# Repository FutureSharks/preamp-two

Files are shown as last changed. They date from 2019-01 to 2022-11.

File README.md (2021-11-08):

# Preamp Two



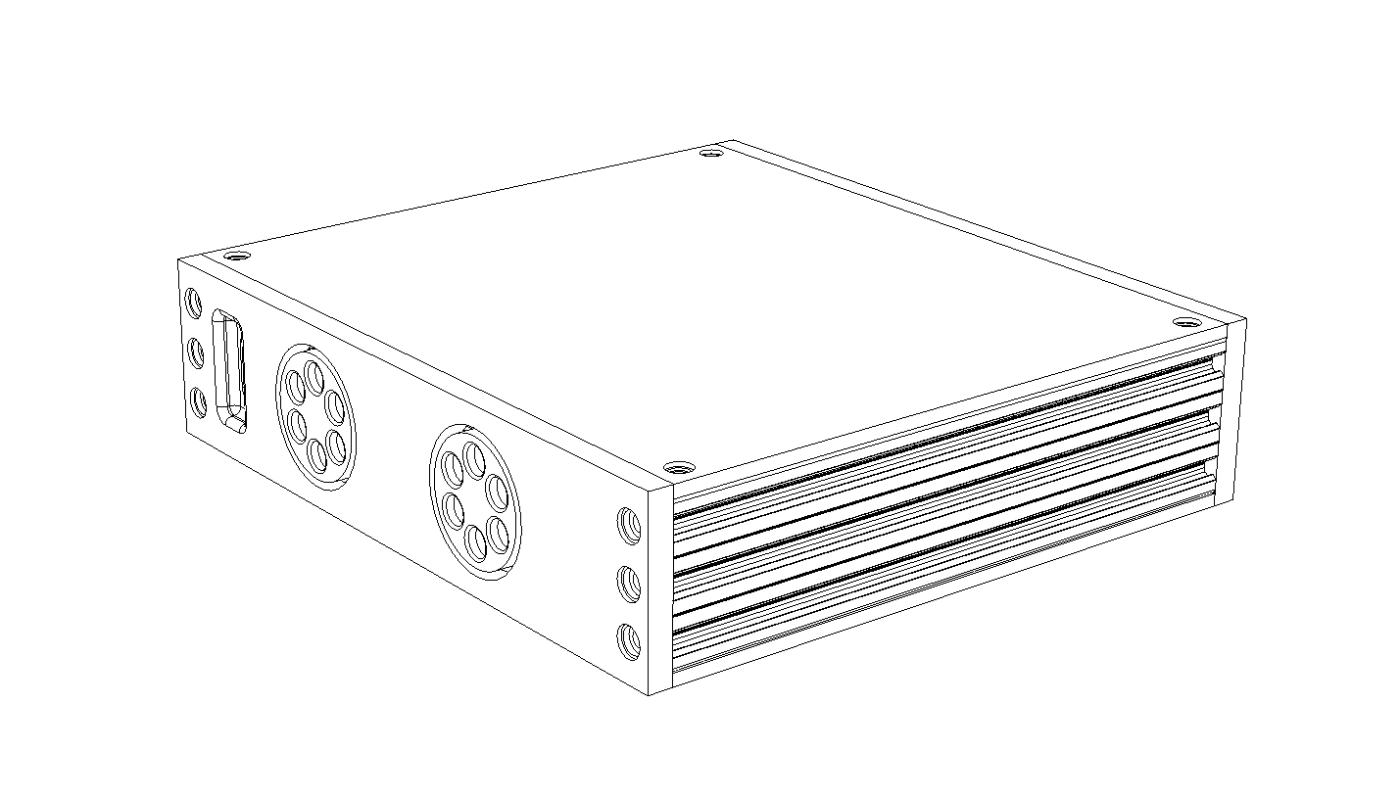
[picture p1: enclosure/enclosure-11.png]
complete


Here is my Hi-Fi preamplifier project. In this repository you can find schematics, PCB layouts, CircuitPython code, BoMs, measurements and photos.

Features:

* MDAC volume controller
* 6 way relay based input selector
* High performance design with measurements
* Quality components and modular design
* Completely digitally controlled
* All open source and written in Python

## Components and code

The preamplifier is made up of a number of connected components:

* MDAC attenuator ([PCB](PCBs/mdac-attenuator), [code](code/modules/mdac_attenuator.py)): Controls the volume
* Input selector ([PCB](PCBs/input-selector), [code](code/modules/input_selector.py)): Selects the input
* Encoder panel ([PCB](PCBs/encoder-panel), [code](code/modules/encoder_panel.py)): Holds rotary encoder and LED indicator ring
* Power Supply 5V ([PCB](PCBs/psu-digital)): Power supply for digital components.
* Power Supply +/- 15V ([PCB](PCBs/psu-analog)): Analog Power supply for MDAC attenuator
* Micro controller board ([PCB](PCBs/mcu-board), [code](code/main.py)): Holds the [Itsy Bitsy M4 Express](https://learn.adafruit.com/introducing-adafruit-itsybitsy-m4?view=all) and other connectors
* RCA panel ([PCB](PCBs/rca-panel)): For the RCA sockets and connectors

The PCBs and schematics were created in [KiCad](http://kicad.org/) and the code that runs on the micro controller is [CircuitPython](https://circuitpython.org/).

## Enclosure

Diagrams, CAD files and other information can be found here: [enclosure](enclosure)

## Measurements

THD, S/N ratio and power consumption: [measurements](measurements)

## Prototypes and testing

See here for a number of different [prototypes](prototypes). All PCBs were made by [OSH Park](https://oshpark.com/).

## Photos

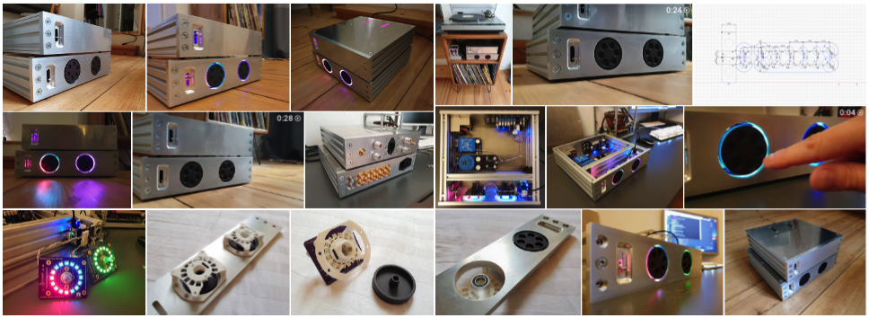
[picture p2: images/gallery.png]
photos


---

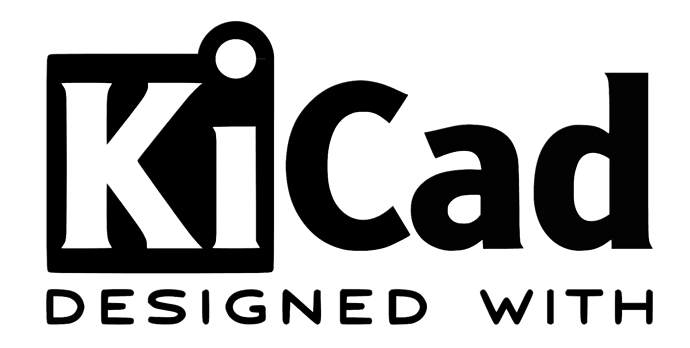
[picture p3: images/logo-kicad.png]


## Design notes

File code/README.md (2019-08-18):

# Code



Here is the code to run on a [CircuitPython](https://circuitpython.org/) micro-controller. Written and tested with Version 4.1.

To copy the code to the micro-controller:

```
cp -a code/modules code/main.py /Volumes/CIRCUITPY/
```

## Modules

- `modules/encoder_panel.py`: Controls the NeoPixel ring and reads the rotary encoder
- `modules/input_selector.py`: Controls the input selector hardware
- `modules/mdac_attenuator.py`: Controls the input attenuator hardware
- `modules/volume_control.py`: Manages the volume control interface
-	`modules/input_control.py`: Manages the input selector interface

---



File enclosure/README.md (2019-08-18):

# Enclosure



The enclosure is based around 2060 extrusion profile. You can buy it at many places. I bought mine [from Aliexpress](https://www.aliexpress.com/wholesale?SearchText=2060%20extrusion) where many sellers will cut custom lengths. It's a great thing to build things from because it's relatively cheap, you can tap an M6 thread into the ends and there's many brackets and attachments available specifically for the whole family of 20xx extrusions.

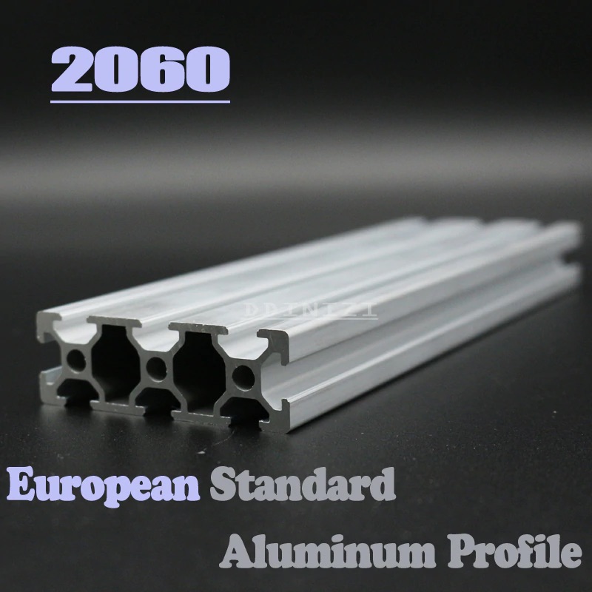
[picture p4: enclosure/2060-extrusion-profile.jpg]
2060-extrusion


## CAD files

Knobs and bearing bracket were made by [Shapeways](https://www.shapeways.com/).

Fusion 360 archive file: [preamp-two-enclosure.f3d](https://github.com/FutureSharks/preamp-two/raw/master/enclosure/preamp-two-enclosure.f3d)

STL of front: [front.stl](front.stl)

STL of rear: [rear.stl](rear.stl)

STL of knob: [knob.stl](knob.stl)

STL of knob and bearing bracket: [bearing-bracket.stl](bearing-bracket.stl)

## Photos



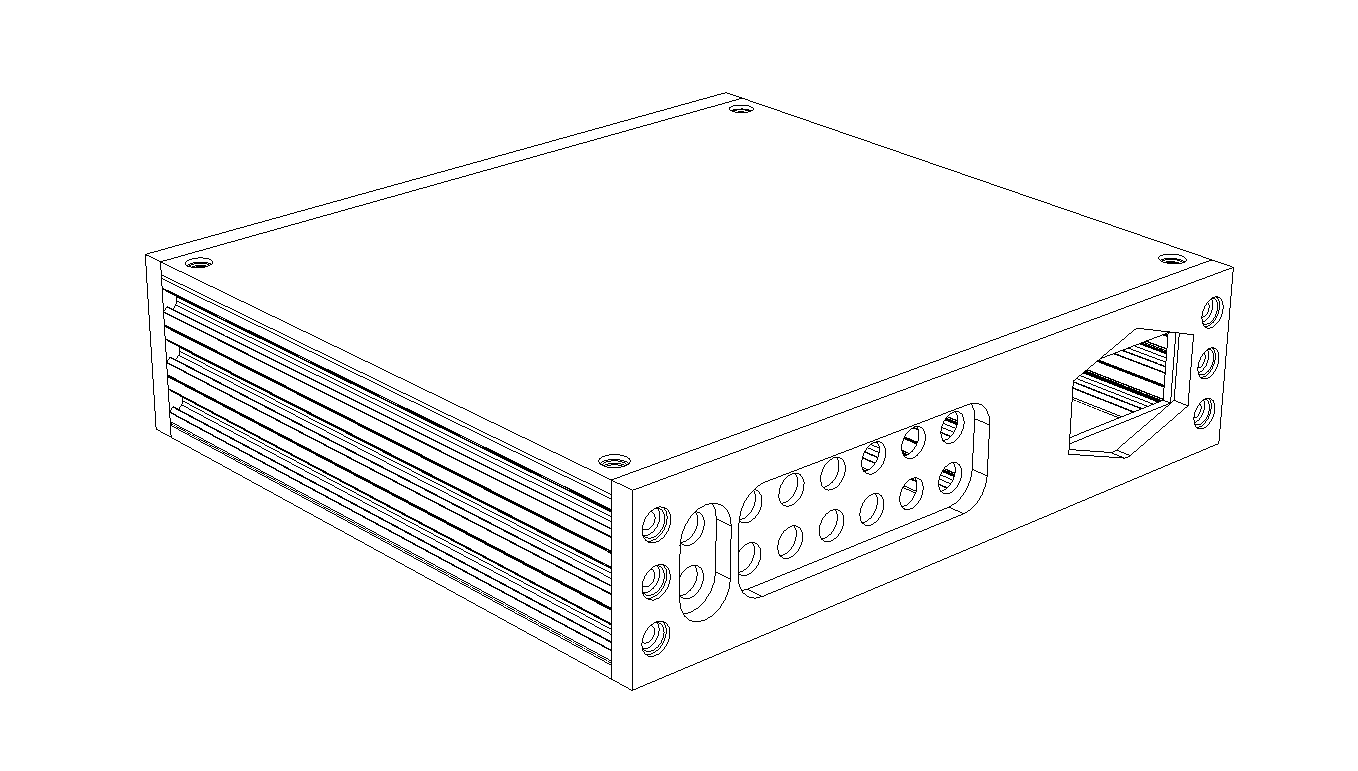
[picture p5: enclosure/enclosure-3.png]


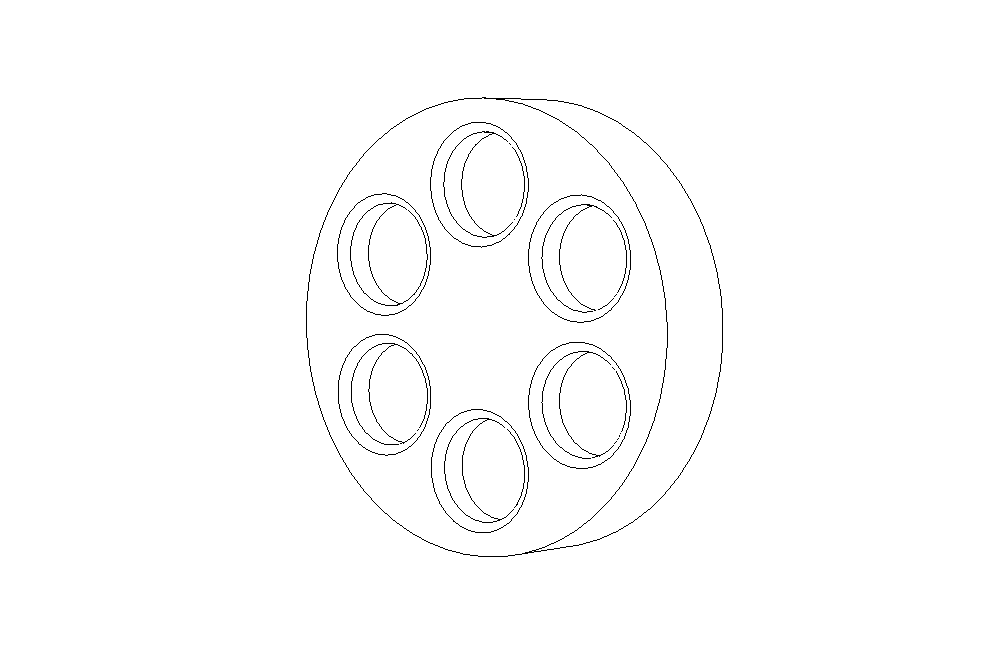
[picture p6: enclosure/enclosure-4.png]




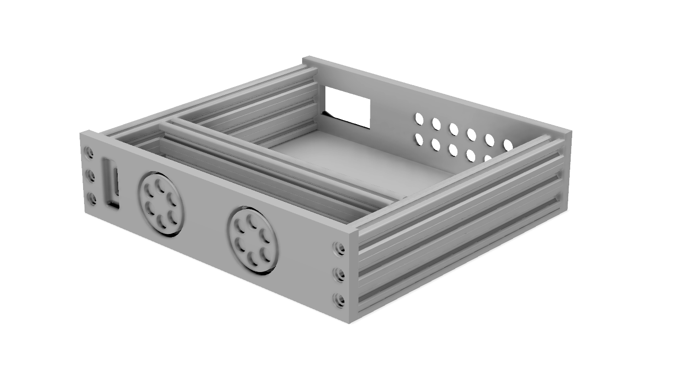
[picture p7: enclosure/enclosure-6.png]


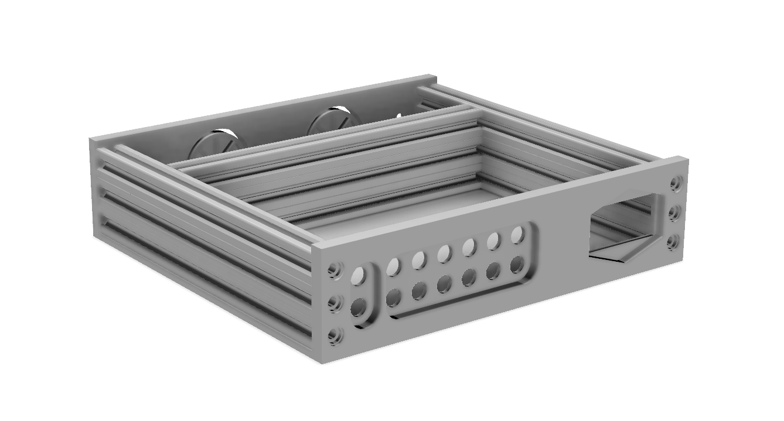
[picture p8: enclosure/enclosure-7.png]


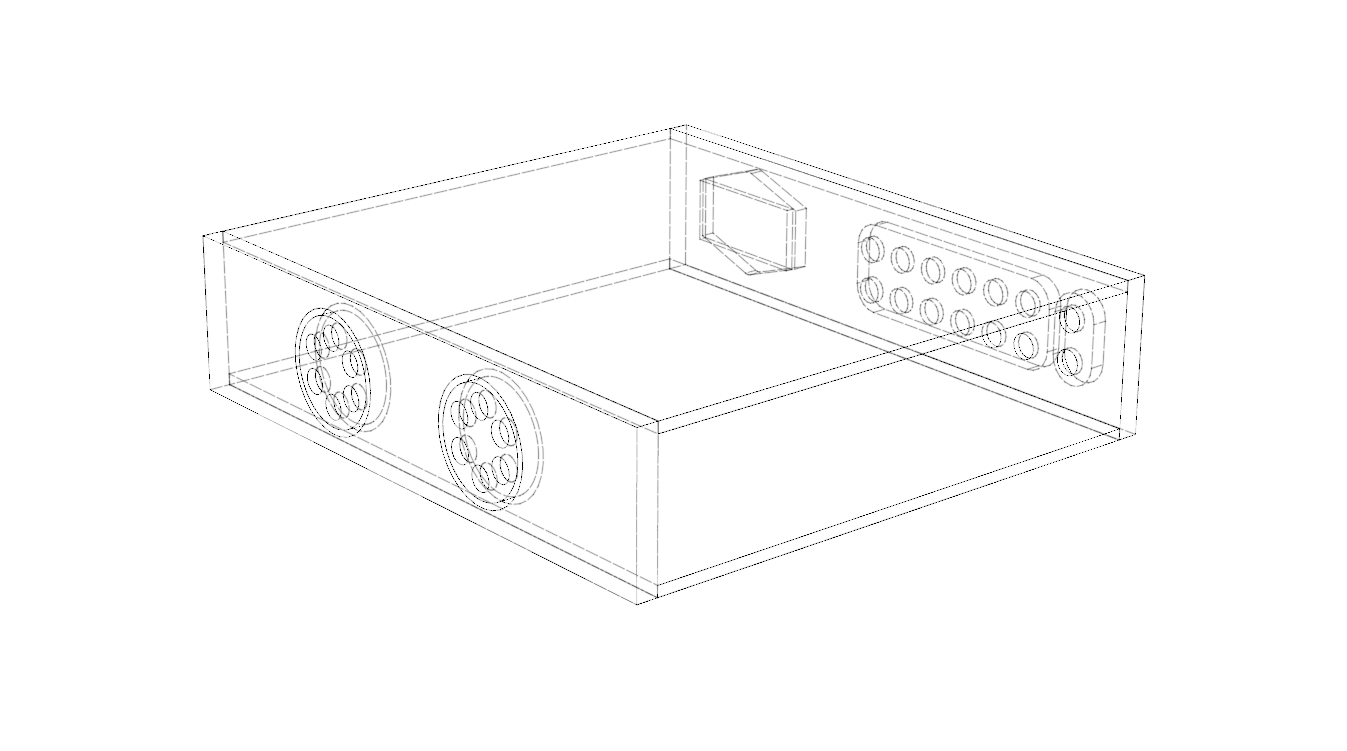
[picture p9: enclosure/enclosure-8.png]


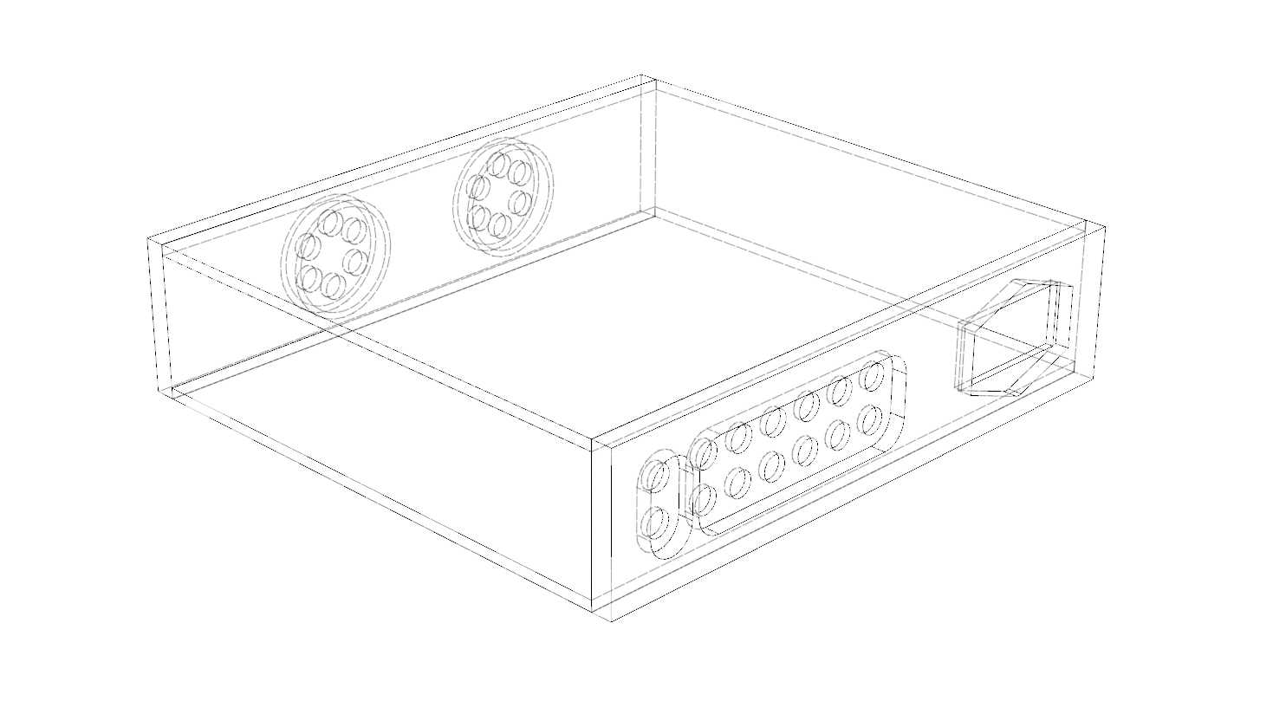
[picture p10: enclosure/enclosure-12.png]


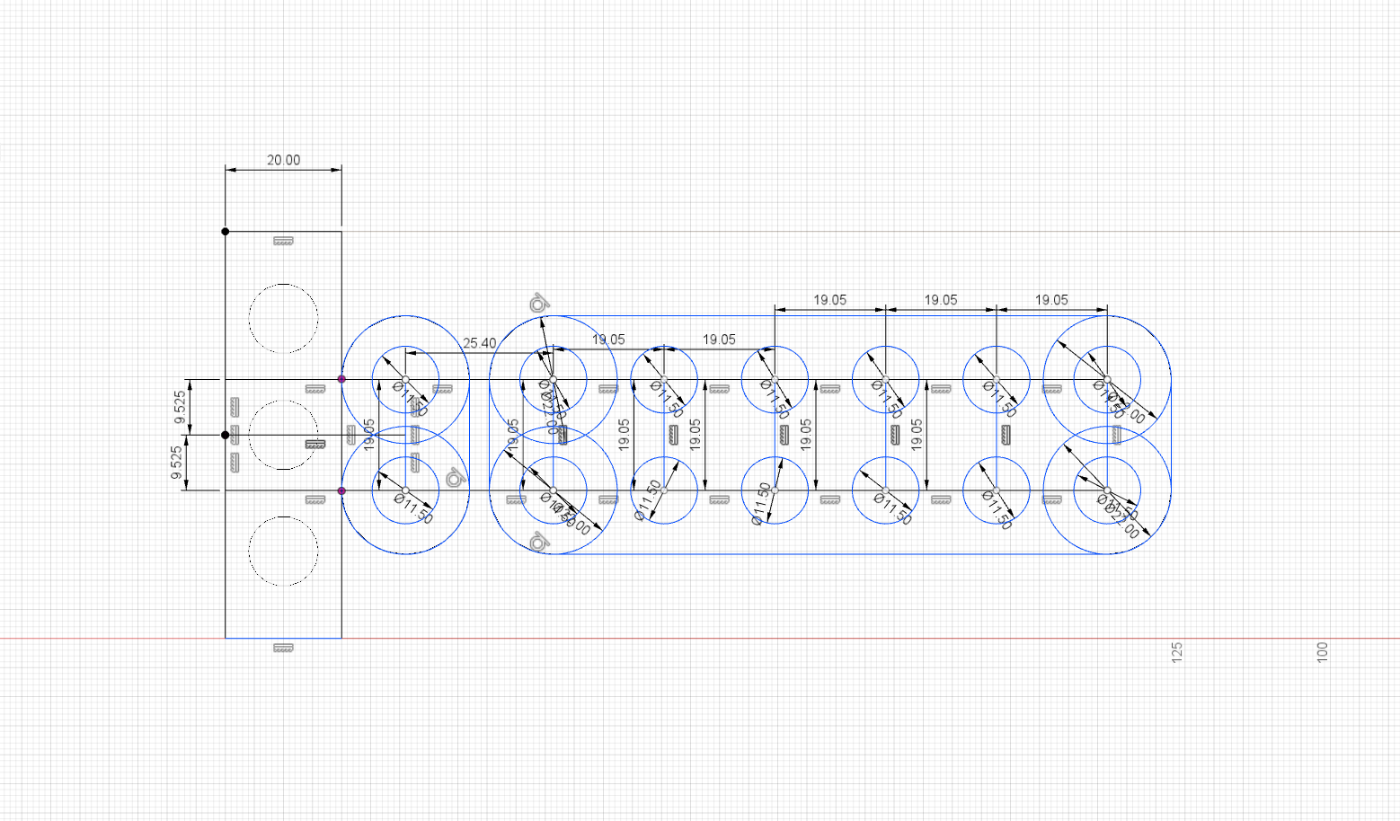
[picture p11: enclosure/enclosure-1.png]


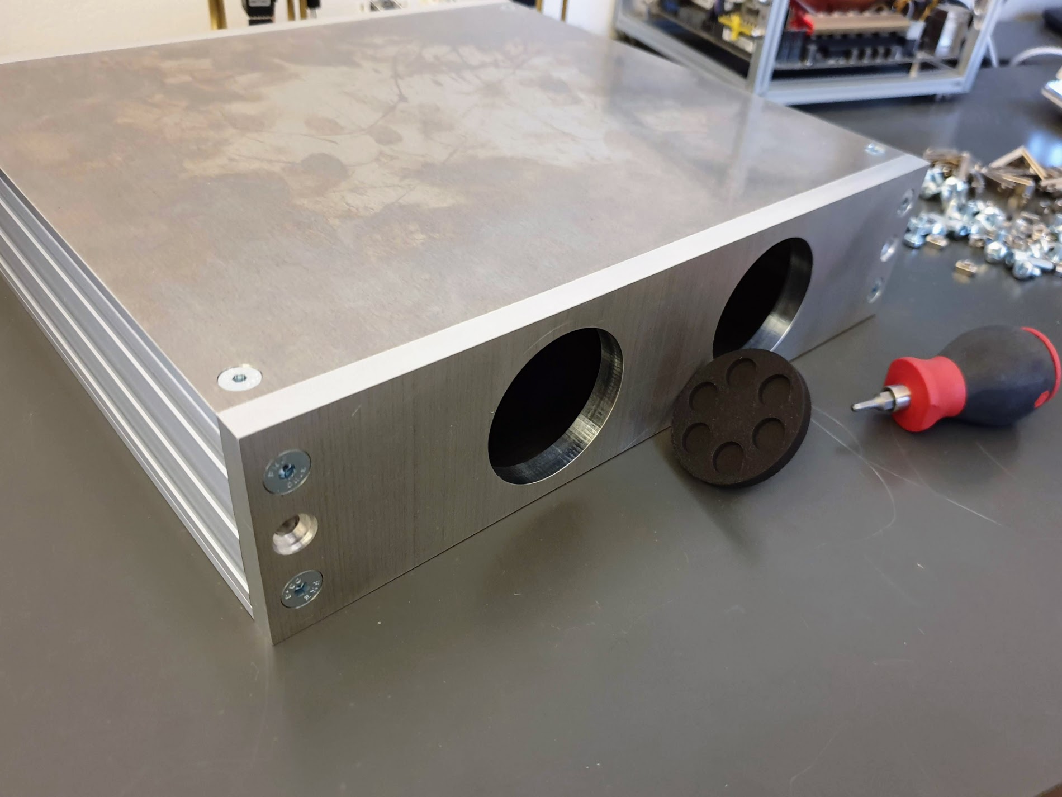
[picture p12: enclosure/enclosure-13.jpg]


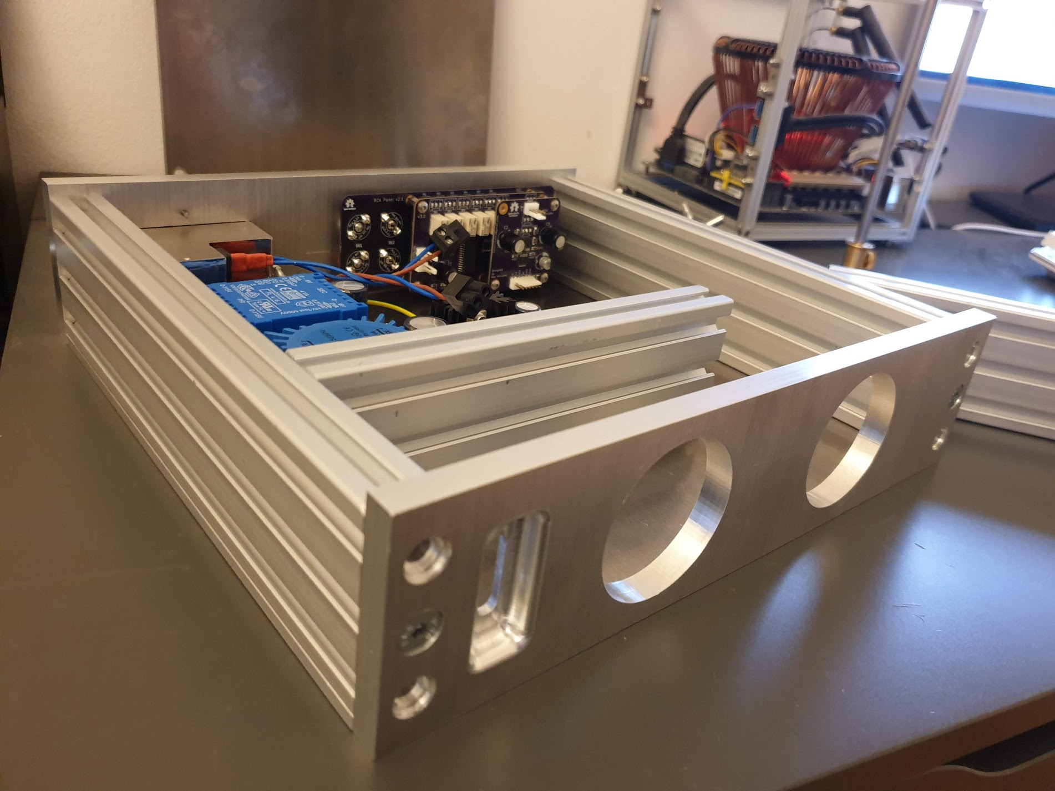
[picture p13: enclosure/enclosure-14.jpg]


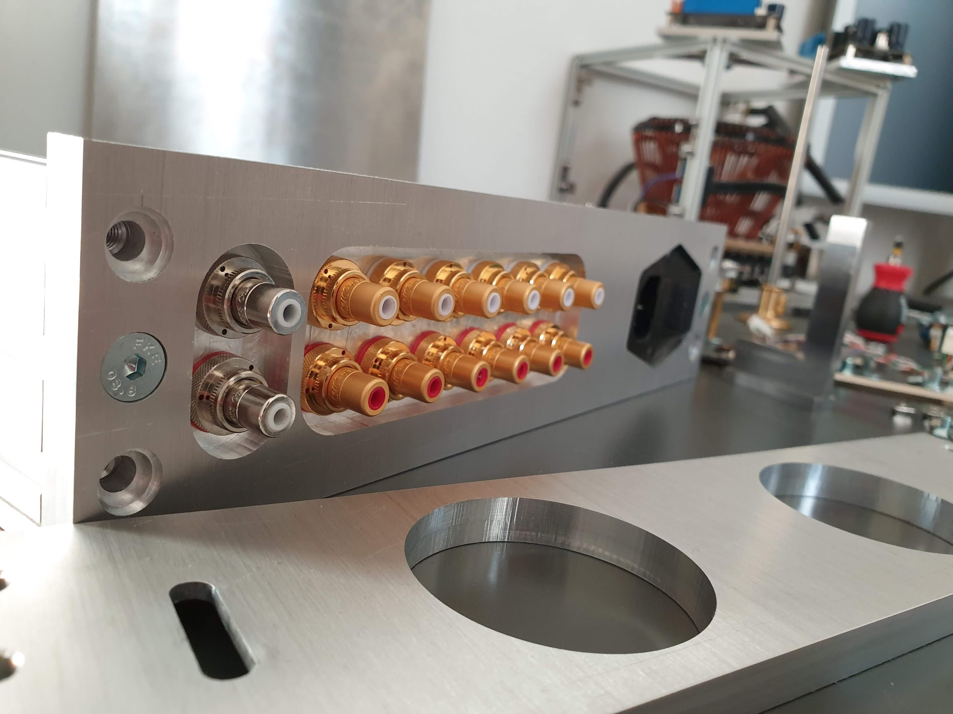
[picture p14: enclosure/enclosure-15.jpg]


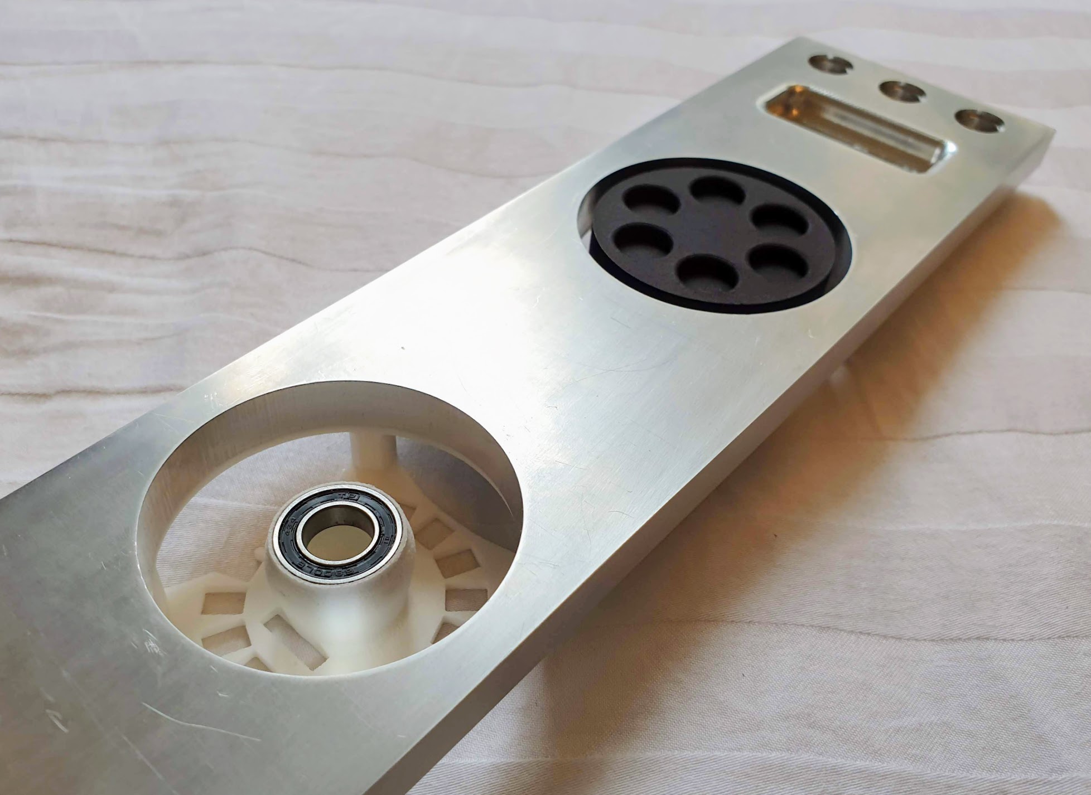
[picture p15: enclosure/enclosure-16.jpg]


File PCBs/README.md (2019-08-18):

# PCBs and schematics



* [MDAC attenuator](mdac-attenuator): A digital attenuator
* [Input selector](input-selector): Relay based input selector
* [Encoder panel](encoder-panel): Holds rotary encoder and LED ring
* [Power Supply 5V](psu-digital): Power supply for digital components.
* [Power Supply +/- 15V](psu-analog): Power supply for MDAC attenuator
* [Micro controller board](mcu-board): Holds the micro controller and other connectors
* [RCA panel](rca-panel): For the RCA sockets and connectors

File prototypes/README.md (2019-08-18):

# Prototypes and testing



I made quite a few test module and prototypes before settling on the current design. Some were successful and others were total failures. I was most interested in having a non-screen based touch interface, either with capacitive sensors or with light sensors. But I couldn't get this to be reliable.

prototype

prototype

prototype

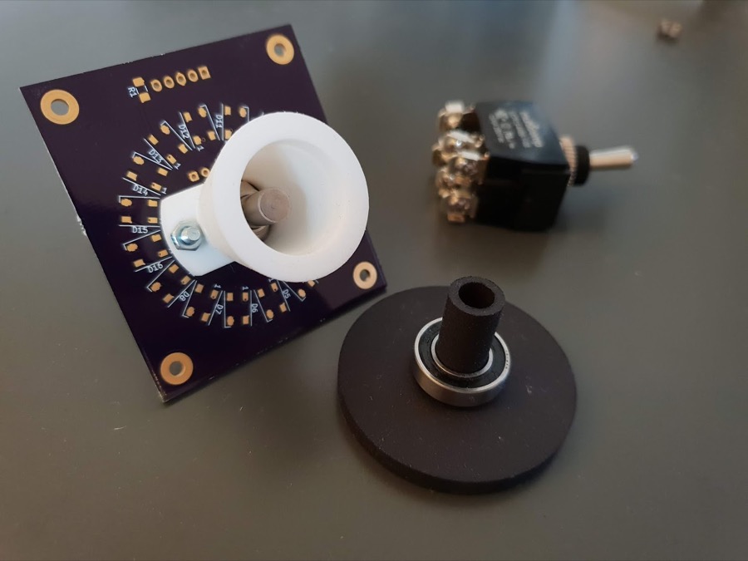
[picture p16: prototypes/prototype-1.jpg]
prototype


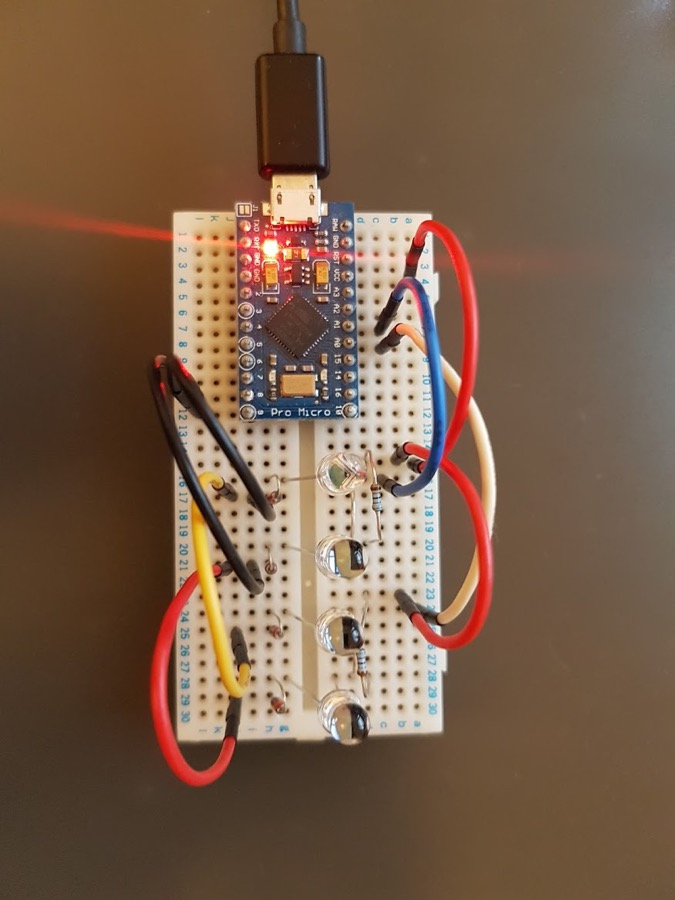
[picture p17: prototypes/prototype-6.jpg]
prototype


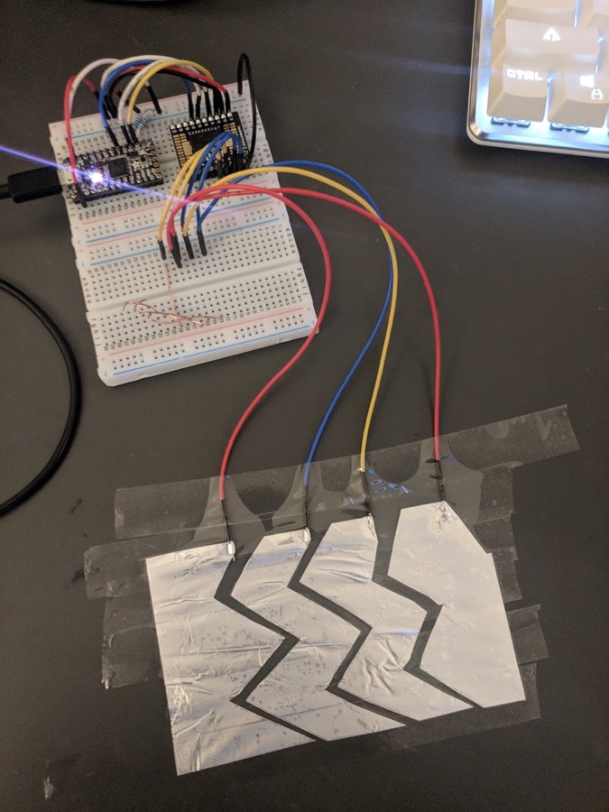
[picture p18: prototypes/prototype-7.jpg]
prototype


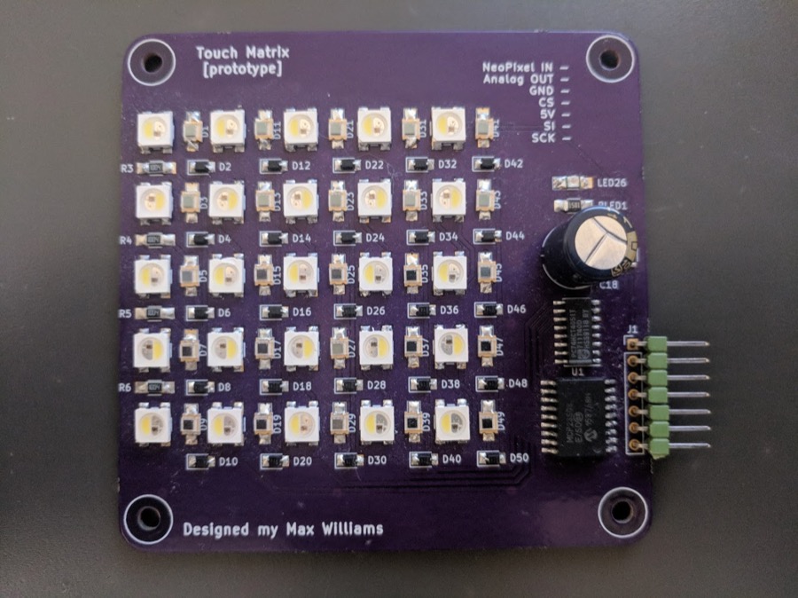
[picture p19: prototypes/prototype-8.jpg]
prototype


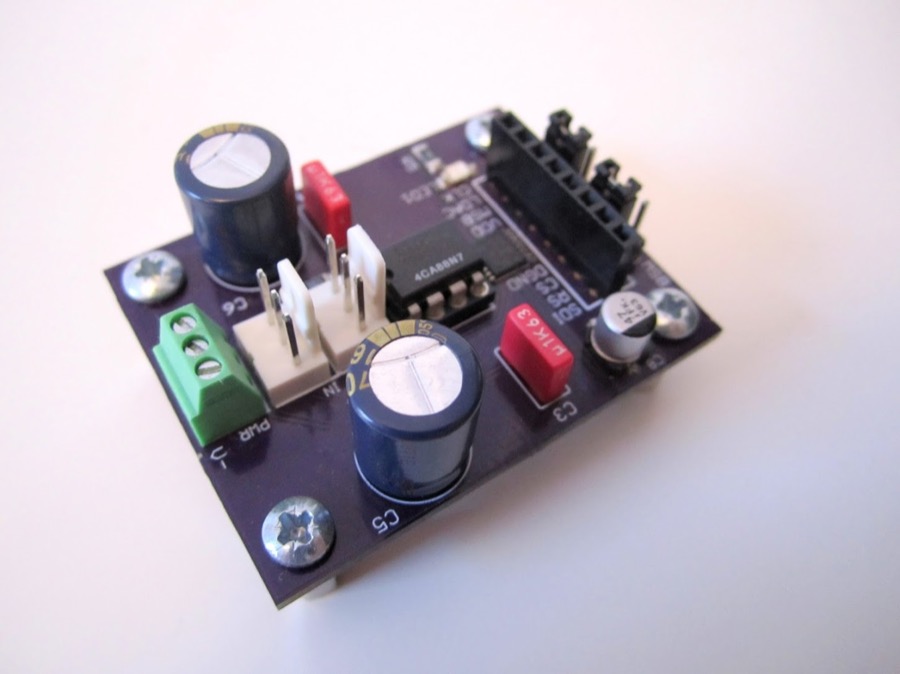
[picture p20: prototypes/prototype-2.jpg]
prototype


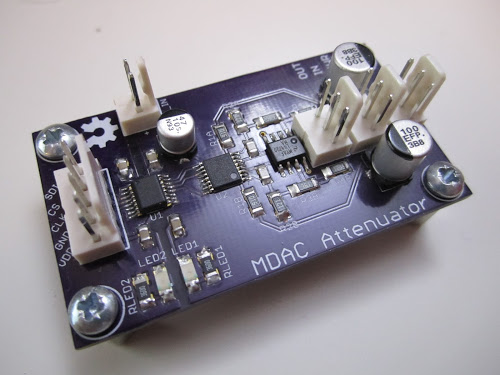
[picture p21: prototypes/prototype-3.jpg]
prototype


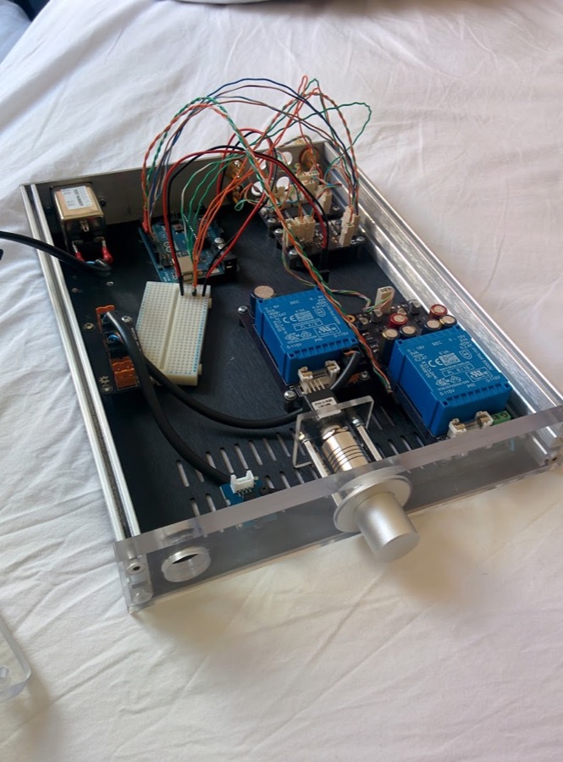
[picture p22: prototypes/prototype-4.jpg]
prototype


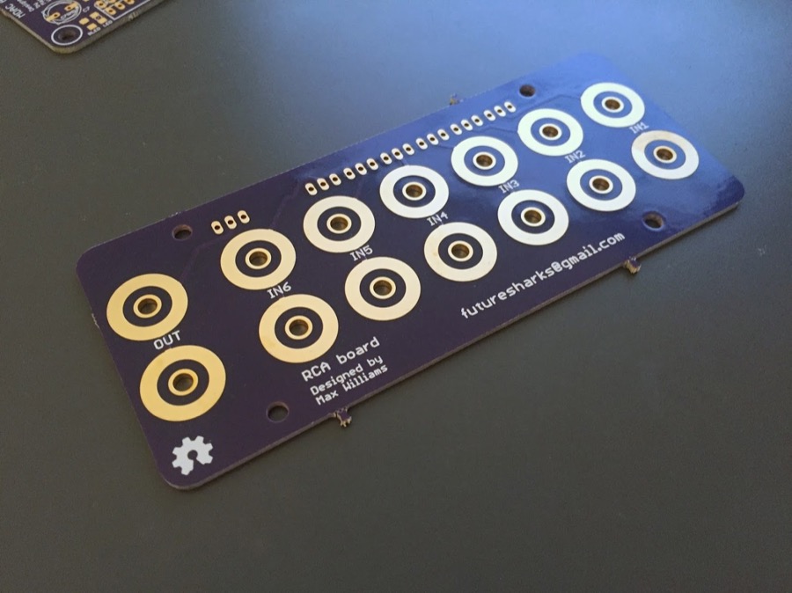
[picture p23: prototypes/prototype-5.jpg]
prototype


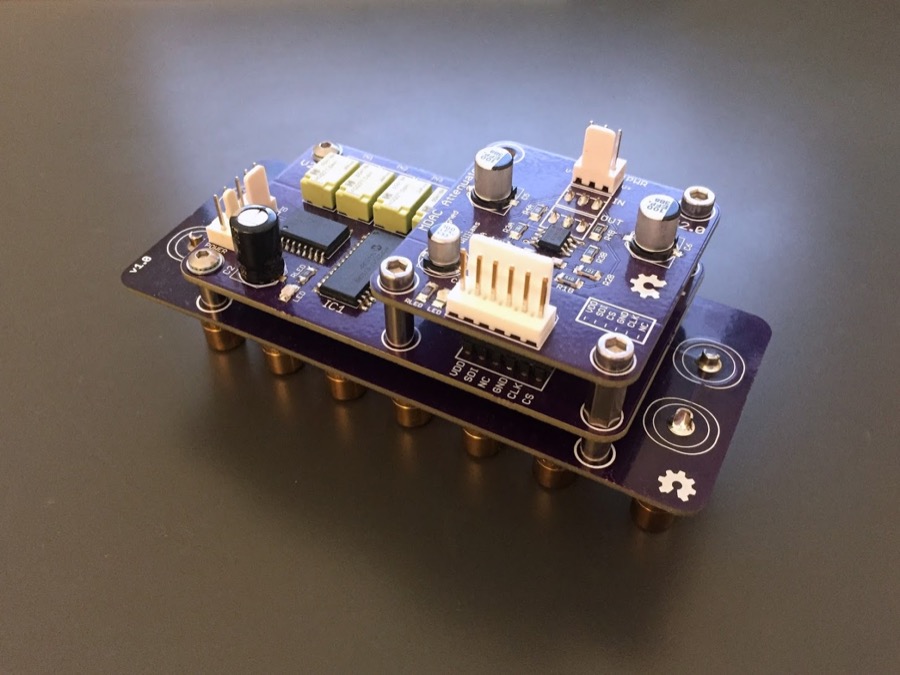
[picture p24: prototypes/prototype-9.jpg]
prototype


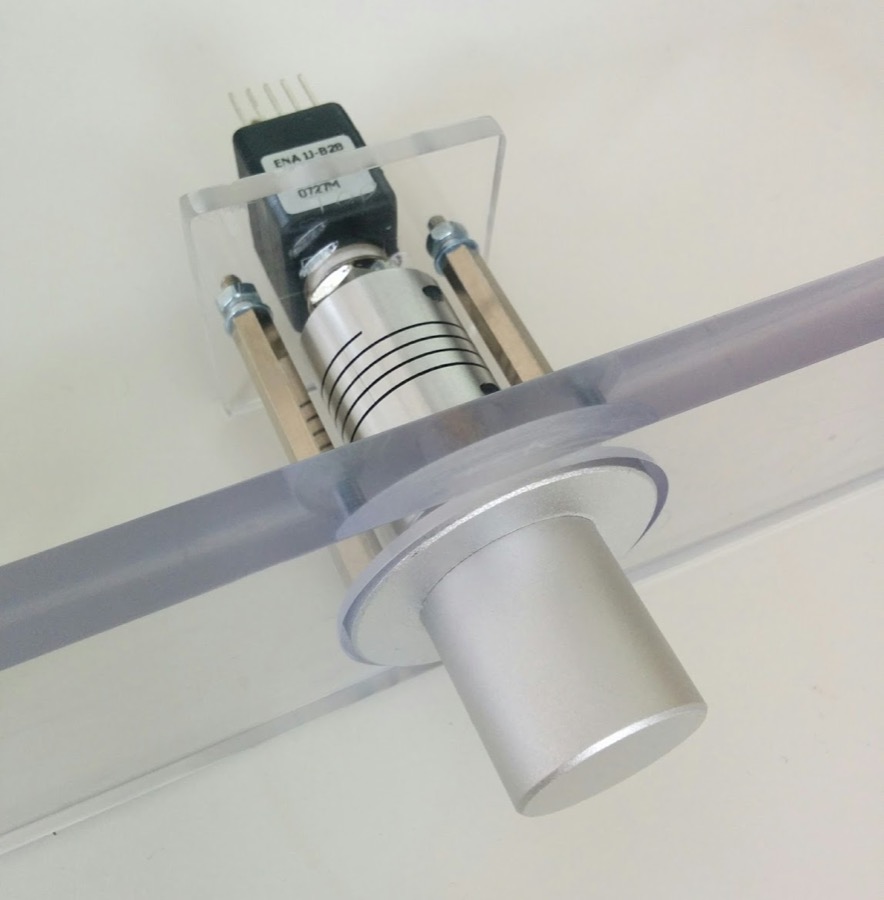
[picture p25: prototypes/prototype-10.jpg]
prototype


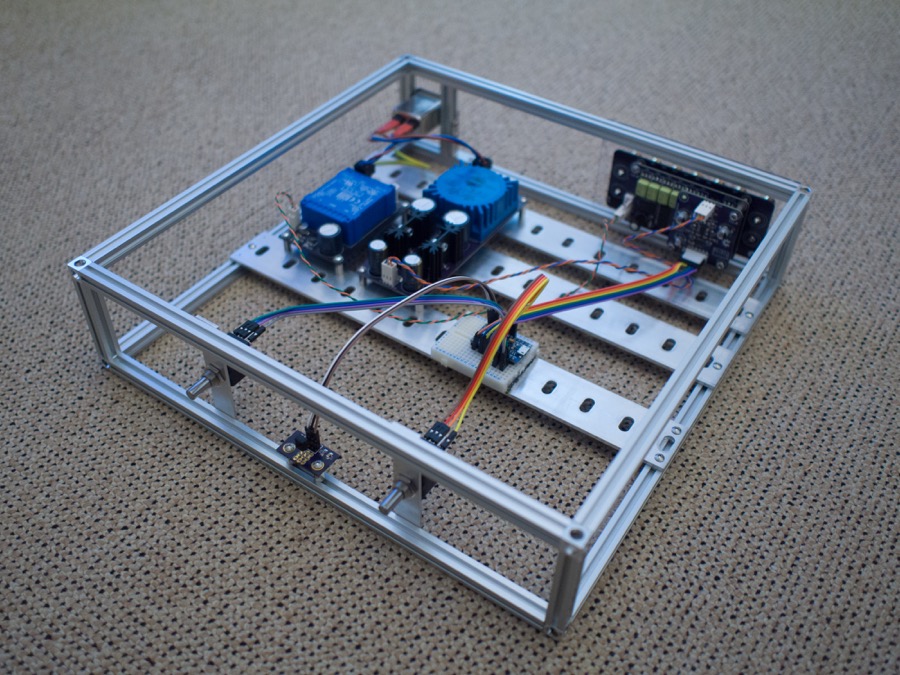
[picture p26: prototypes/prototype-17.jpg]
prototype


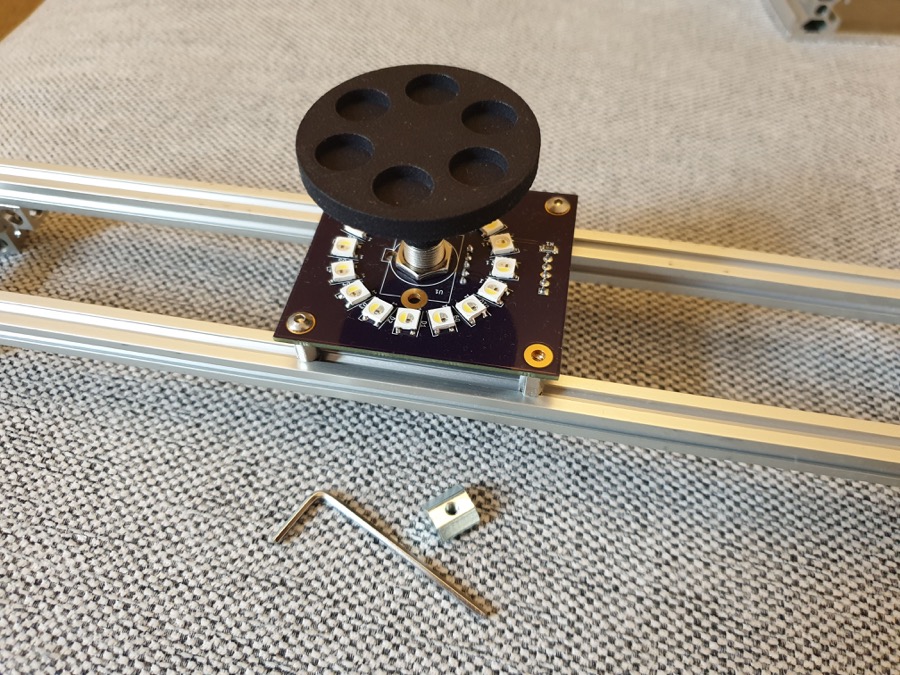
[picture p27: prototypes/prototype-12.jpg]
prototype


prototype

prototype

prototype

prototype

prototype

prototype

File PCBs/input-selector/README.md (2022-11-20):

# Input Selector



* 6x inputs
* Mute for output
* SPI controlled using a MCP23S17
* Latching relays for low current draw
* Compatible with 5V and 3V relays
* Uses high quality Panasonic relays
* Stackable with [RCA panel](../rca-panel) and [MDAC attenuator](../mdac-attenuator)

## Photos









##  Code

Python module is here: [code/modules/input_selector.py](../../code/modules/input_selector.py)

## Schematic



## Layout





## BoM

| Reference |  Quantity |  Value |  Footprint / Notes |
|---|---|---|---|
| C2, C3, C4 | 3 | 100nF | 1206 |
| C1_SMD | 1 | 100uF | Radial 10/5mm or SMD, 10V or higher |
| IN1-6, MUTE_IN1, MUTE_OUT1, SELECTOR_OUT1 | 9 | 1x3 | Molex KK 254, Multicomp MC34 or any 0.1" socket header |
| J1 | 1 | 1x6 | Molex KK 254, Multicomp MC34 or any 0.1" socket header |
| EXTRA_IO1, PWR1 | 2 | 1x2 | Molex KK 254, Multicomp MC34 or any 0.1" socket header |
| K1-K6 | 6 | G6JU-2P-Y-DC3 | 3V latching coil. e.g. Omron G6J, Panasonic AGN or Tyco IM narrow |
| MUTE1 | 1 | G6J-2P-Y-DC3 | 3V non-latching coil. e.g. Omron G6J, Panasonic AGN or Tyco IM narrow |
| R1-9 | 12 | 47R | 1206 |
| RLED1 | 1 | 1K | 1206 |
| LED1 | 1 | - | 1206 |
| U1, U3 | 2 | ULN2003V12DR | SOIC-16 |
| U2 | 1 | MCP23S17-E/SO | SOIC 28 wide |

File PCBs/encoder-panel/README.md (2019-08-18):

# Encoder Panel



The module is the sole human interface to the preamp. It consists of 2 things:

- A high quality optical encoder for changing of the volume and input
- A ring of [NeoPixels](https://learn.adafruit.com/adafruit-neopixel-uberguide/the-magic-of-neopixels) as a visual indicator and to give feedback

## Photos











##  Code

Python module is here: [code/modules/encoder_panel.py](../../code/modules/encoder_panel.py)

## Schematic



## Layout





## BoM

| Reference  | Quantity | Value | Footprint |
|---|---|---|---|
| C1-16 | 16 | 0.1uF | Capacitor SMD 1206 |
| C17, C18 | 2 | 1000uF | Capacitor SMD 8x5.4 or Capacitor THT D8.0mm P5.00mm |
| D1-16 | 16 | WS2812B | LED SMD WS2812B |
| J1 | 1 | Conn_01x05  | Molex_KK-254_AE-6410-05A_1x05_P2.54mm_Vertical |
| R1 | 1 | 500R | Resistor SMD 1206 |
| U1 | 1 | ENA1J-B28 | Bourns ENA1J-B28-L00128L |

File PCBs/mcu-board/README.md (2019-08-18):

# Micro controller board



The PCB holds the [Adafruit ItsyBitsy M4 Express](https://learn.adafruit.com/introducing-adafruit-itsybitsy-m4), connectors and level shifters. The MDAC attenuator, input selector, both encoder panels and power digital power supply all connect to this PCB.

## Photos











##  Code

The main python code is here: [main.py](../../code/main.py)

## Schematic



## Layout





## BoM

| Reference | Quantity | Value | Footprint |
|---|---|---|---|
| U1 | 1 | m0-express | Adafruit ItsyBitsy M4 Express |
| U2, U3 | 2 | SN74AHCT125D | Package_SO:SOIC-14_3.9x8.7mm_P1.27mm |
| LED_3V1, LED_5V1 | 2 | LED | LED SMD 1206 |
| RLED1, RLED2 | 2 | R | Resistor SMD 1206 |
| C1, C2 | 2 | C | Capactior SMD 1206 |
| ENCODER-PANEL-1  | 1 | ENCODER-PANEL-1 | Molex_KK-254_AE-6410-05A_1x05_P2.54mm_Vertical |
| ENCODER-PANEL-2  | 1 | ENCODER-PANEL-2 | Molex_KK-254_AE-6410-05A_1x05_P2.54mm_Vertical |
| IR1 | 1 | Conn_01x03 | Molex_KK-254_AE-6410-03A_1x03_P2.54mm_Vertical |
| J5 | 1 | MDAC-INPUT-SELECTOR | Molex_KK-254_AE-6410-06A_1x06_P2.54mm_Vertical |
| 3.3V1 | 1 | 3.3V | Molex_KK-254_AE-6410-02A_1x02_P2.54mm_Vertical |
| 5V1 | 1 | 5V | Molex_KK-254_AE-6410-02A_1x02_P2.54mm_Vertical |
| VBAT1 | 1 | V-BAT | Molex_KK-254_AE-6410-02A_1x02_P2.54mm_Vertical |

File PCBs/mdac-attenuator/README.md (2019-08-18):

# MDAC attenuator



Based on designs from these sources:

- [Precision, AC Reference Signal Attenuator Using the AD5546/AD5556 Multiplying DAC](https://www.analog.com/media/en/technical-documentation/application-notes/AN-1488.pdf)
- [New High-Resolution Multiplying DACs Excel at Handling AC Signals](https://www.analog.com/en/analog-dialogue/articles/high-resolution-multiplying-dacs.html)

This design is also used by a number manufacturers:

- Mark Levinson preamps
- Luxman LECUA (Luxman Electronically Controlled Ultimate Attenuator)
- Accuphase [AAVA](http://www.accuphase.com/aava.html)

Features:

* 65536 linear steps
* Gain possible, set by op-amp and resistors
* Excellent performance
* Can drive headphones
* Compact
* SPI controlled

Here is the DIYAudio forum thread with my prototypes and questions: [Solid state R2R attenuator using analog switches or multiplying DAC](https://www.diyaudio.com/forums/analog-line-level/235853-solid-r2r-attenuator-using-analog-switches-multiplying-dac.html)

## Photos









##  Code

Python module is here: [code/modules/mdac_attenuator.py](../../code/modules/mdac_attenuator.py)

## Schematic



## Layout





## BoM

| Reference |  Quantity |  Value  |  Footprint / Notes  |
|---|---|---|---|
| C1A1, C1B1 | 2 | 2pF | 0805 |
| C4, C6, C7 | 3 | 100nF | 1206 |
| C2, C3, C5 | 3 | 100uF | Radial 10/5mm or SMD |
| IN1, OUT1, PWR1 | 3 | 1x3 | Molex KK 254, Multicomp MC34 or any 0.1" socket header |
| J1 | 1 | 1x6 | Molex KK 254, Multicomp MC34 or any 0.1" socket header |
| J2 | 1 | 1x6 | 0.1" socket header, for passthrough to input-selector |
| LED1 | 1 | LED | 1206 |
| R1 | 1 | RLED | 1206 |
| R1A1, R1B1 | 2 | 91R | 1206 |
| R2A1, R2B1, R4A1, R4B1 | 4 | 120R | 1206 |
| R3A1, R3B1 | 2 | 360R | 1206 |
| U1 | 1 | AD8599ARZ | SOIC-8 |
| U2 | 1 | DAC8812ICPWG4 | TSSOP-16 | Can also use AD5545

Values for R1, R2 and R3 above give a gain of 4.

To calculate gain use this formula:

```
gain = (R2+R3)/R2
R1 = (R2*R3)/(R2+R3)
```

Refer to the [AD5429/AD5439/AD5449 datasheet](http://www.analog.com/media/en/technical-documentation/data-sheets/AD5429_5439_5449.pdf)

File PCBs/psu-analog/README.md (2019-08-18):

# Analog Power Supply



This the +/- 15V power supply. It powers the op-amp in the MDAC attenuator using TPS7A3301 regulators.

The PCB files are in Eagle format.

## Photos





## Schematic



## Layout



## BoM

|  Part name | RS part | Farnell Part | Mouser Part | Description | EVM Part name | Notes |
| --- | --- | --- | --- | --- | --- | --- |
| C1/C2 | 571319 | | 667-EEU-FC1V182S | Large input cap, 7.5mm/18mm | - | |
| C5/C6 | - | | 80-C1206C104K5R | 1206, 0.1uF, X5R or X7R | - | |
| C7/C8 | 7900610 | | 81-GRM31CR61H106KA2L | 1206, 47uF, X5R or X7R, 2220 package | C1 | |
| C3A/B | 7236657 | | 81-GRM31MR71H105KA88 | 1206, 1uF, X5R or X7R | C3 | NR/SS |
| C4A/B | 2644141 | | 80-C1206C103K1R | 1206, 10nF/0.01uF, X5R or X7R | C4 | CFF/CBYP |
| C9-14 | 7900610 | | 81-GRM31CR61H106KA2L | 1206, 22-15uF, multiple, 2220 package | C5-C9 | Total at least 47uF  |
| C15/C16 | 571408 or 571290 | | 667-EEU-FC1E102 | Large output cap, 5mm/13mm | C10 | |
| R1A/B | | | 667-ERJ-8ENF1244V | 1.24M | R1 | Value for -15VDC |
| R2A/B | | | 667-ERJ-8ENF1053V | 105K | R2 | Value for -15VDC |
| B1/2 | 8148800 | 1336500 | 625-DFL1508S-E3/77 | VISHAY - DFL1508S-E3/45, BRIDGE RECTIFIER | | |
| IC1/IC2 | | | 595-TPS7A3301KC | LDO Voltage Regulators -3 to -36V,-1A,Ultra Low Noise,High PSRR | | |
| TR1 | 2239216 | | | Block FL6/FL8, Talema/Amveco 5/7VA or standard EI-42 | | |
| F1 | 7874164 | | 576-64900001039 | 5x20mm Fuseholder 6.3A 250V | | |
| AC | 403932 | | | 5.08mm Pitch 2 Way 1 Row Straight PCB Header | | AC in |
| KK1/KK2 | | | 532-513002B25G | | | Heatsinks, SK104-PAD |
| LED | - | - | - | Any 1206 LED | | |
| RLED | - | - | - | To match LEDs | | |
| X2 | | | | | | Power out |
| Fuse | | | 530-5ST63-R | 5x20mm, 63mA | | |

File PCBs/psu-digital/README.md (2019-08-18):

# Digital Power Supply



This the 5V digital power supply. It powers the input selector, digital part of the MDAC attenuator, the NeoPixels in the encoder panels and the encoders.

It uses a LT1763 regulator.

The PCB files are in Eagle format.

## Photos



## Schematic



## Layout



## BoM

| Reference | Footprint / Notes  |
|---|---|
| F1 | Fuse holder. |
| TR1 | Pads for Block FL2/FL4/FL6/FL8 or EI38 or EI30. Ideally 2x 6VAC. |
| B1 | VISHAY DFL1508S bridge rectifier. |
| C1 | Panasonic FC 1500UF, 16V. |
| L1 | INDUCTOR, 1210 CASE, 10UH. |
| L2 | FERRITE BEAD, 0.1OHM, 2A, 1206. |
| C2 | 100nF X7R, 1206 package. |
| IC1 | LT1763CS8-5, 5V fixed regulator. |
| C3 | C0G/NP0, 10NF, 100V, 1206 package. |
| C4 | Panasonic FK 100UF, 6.3V, SMD. |
| C5 | 100nF X7R, 1206 package. |
| R1 | Resistor for LED, 1206 package. |
| LED | 1206 LED |

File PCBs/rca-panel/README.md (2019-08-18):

# RCA Panel



This PCB provides mounting for the RCA sockets and connects with the [input selector](../input-selector).

The RCA sockets are [CMC](http://www.audio-cmc.com/rca-jacks-c.html) 805 model.

## Photos











## Schematic



## Layout



## BoM

| Reference |  Quantity |  Value  |  Footprint / Notes  |
|---|---|---|---|
| IN1-6, OUT1 | 7 | 1x3 | Molex KK 254, Multicomp MC34 or any 0.1" socket header |
| RCAs | 14 | - | Any CMC USA 805 |

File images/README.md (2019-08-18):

# Images









 































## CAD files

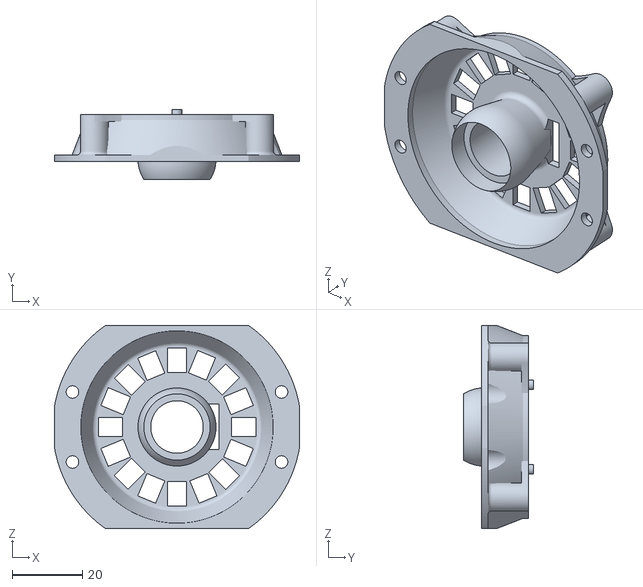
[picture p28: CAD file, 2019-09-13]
enclosure/bearing-bracket.stl
70.0 x 20.0 x 58.0

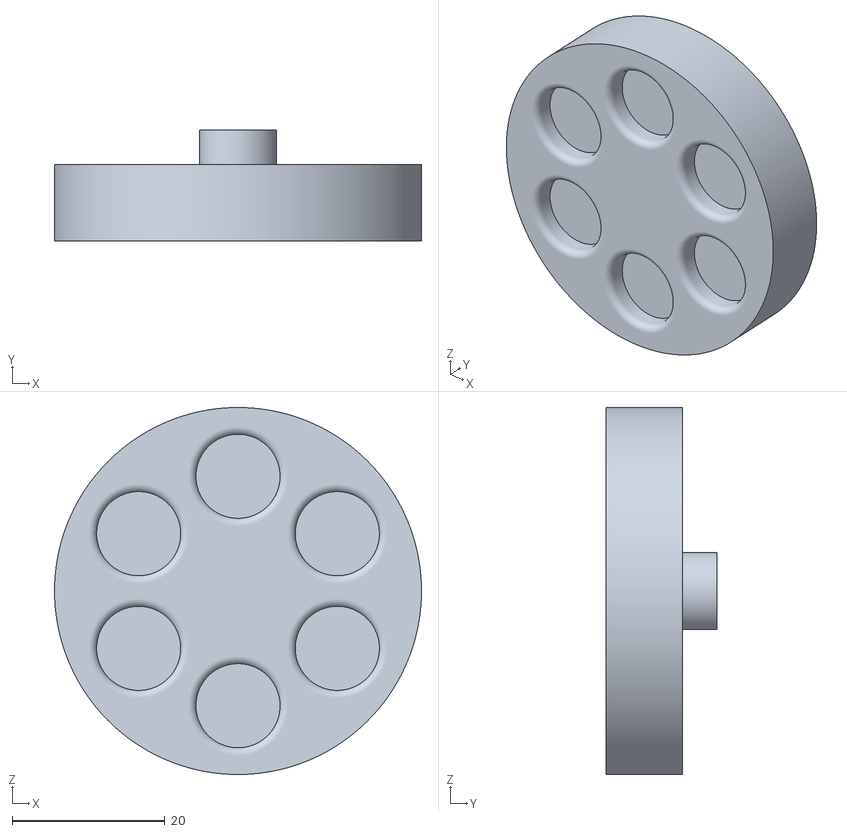
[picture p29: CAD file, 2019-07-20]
enclosure/knob.stl
48.0 x 14.5 x 48.0

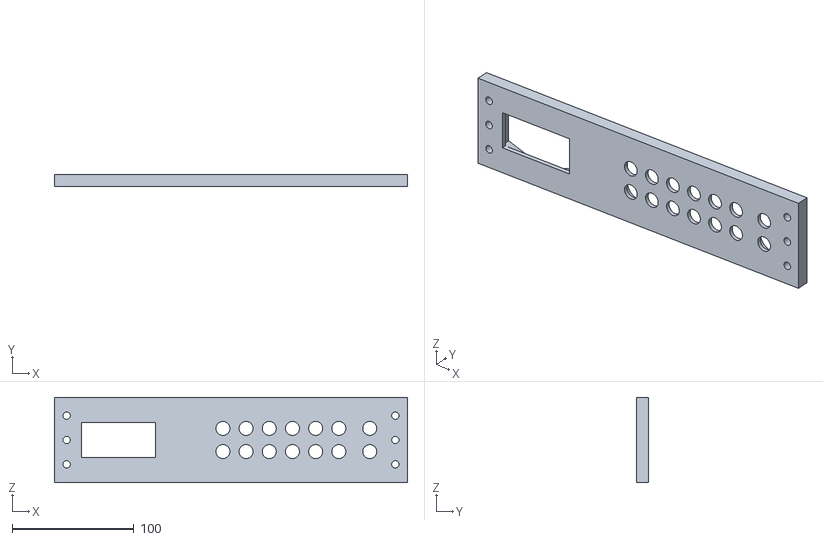
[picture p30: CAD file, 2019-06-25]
enclosure/rear.stl
290.0 x 10.0 x 70.0

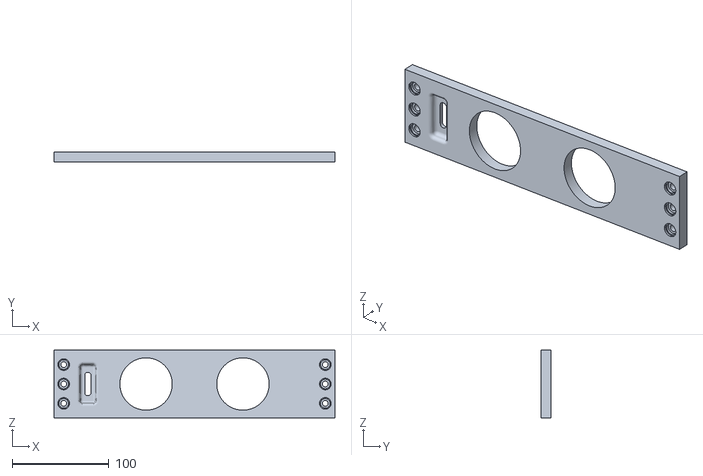
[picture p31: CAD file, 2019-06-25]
enclosure/front.stl
290.0 x 10.0 x 70.0

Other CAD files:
enclosure/preamp-two-enclosure.f3d

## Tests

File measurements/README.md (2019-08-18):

# Measurements



## THD and S/N ratio

Measured with an Asus Xonar Essence STX and [Arta](http://www.artalabs.hr/):

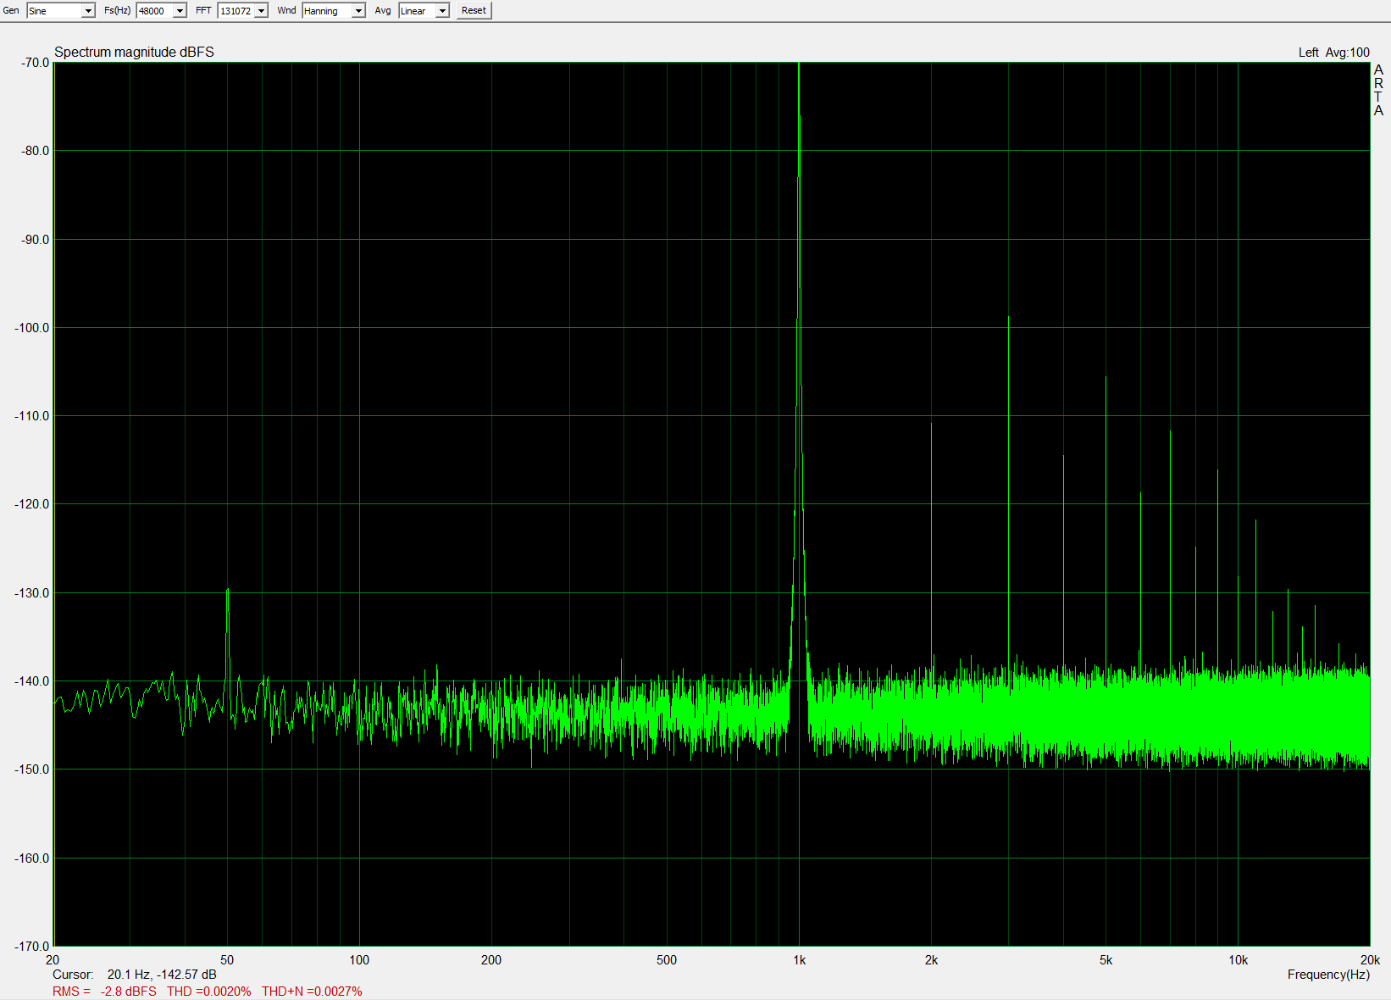
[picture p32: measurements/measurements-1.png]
measurements-1


## Power consumption

4.0 Watts

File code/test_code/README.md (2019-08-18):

# Test code



Here you can find some random Arduino and CircuitPython code for testing each component individually.

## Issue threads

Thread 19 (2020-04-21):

...what about a balanced version ?

forart, 2020-04-21:
It would be very interesting to have a balanced (XLR/TRS) version of the preamp.

Check out this interesting project: https://github.com/gkeeth/preamp-2019

Hope that inspires !

FutureSharks, 2020-04-21:
Hi @forart

Thanks for the message.

> It would be very interesting to have a balanced (XLR/TRS) version of the preamp.

Sure, pull requests or forks welcome 🙂

> Check out this interesting project: https://github.com/gkeeth/preamp-2019

Looks interesting but the BoMs and schematic/layouts are unreadable on Gtihub. This person could improve readability by simply:

- Converting CSV BoMs to [here](https://donatstudios.com/CsvToMarkdownTable)
- Generate renders of PCBs using kicad, it's super easy and quick
- Showing schematics as images

forart, 2020-04-22:
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
Please, post these suggestions in his/their gh !

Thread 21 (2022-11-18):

Input selector [no issue, questions]

zigotica, 2022-11-18:
Hi Max,

I was about to buy the BOM for the input selector, too long inside a box in the closet.

1. What is the expected voltage rating for C1_SMD?
2. Whatever value for RLED1 is fine?
3. Whatever color or specs for LED1 is fine?
4. Can I simply fill in 3 channels instead of 6?
5. What is the expected power supply and do the 2 power inputs need to be isolated?

Thank you so much

FutureSharks, 2022-11-20:
Hi @zigotica 👋

1. It just needs to be higher than the power supply voltage, so higher than 5V. So 10V is a good value.
2. I used 1K so the LED isn't too bright
3. Whatever you want!
4. Yep! Might be better to update the code though, otherwise you will be waiting for it to cycle through the unused inputs
5. 5 volt

I hope that helps 🙂

zigotica, 2022-11-20:
Thank you so much for the answers!

My real problem now is [MCP23S17-E/SO](https://www.mouser.es/ProductDetail/579-MCP23S17-E-SO) and all its family are unavailable at Mouser and Digikey... You don't know of an alternative SPI expander from another manufacturer, do you? May'23 seems a bit too long for just one piece.

Thank you

FutureSharks, 2022-11-21:
I don't think you can use another part in the PCB in place of the `MCP23S17-E/SO`. I'm sure you can find one on eBay or Aliexpress though 🙂

zigotica, 2022-11-21:
Ah yes, didn't think about those. Already bought at Ali. Thank you!

Closed 2022-11-21.

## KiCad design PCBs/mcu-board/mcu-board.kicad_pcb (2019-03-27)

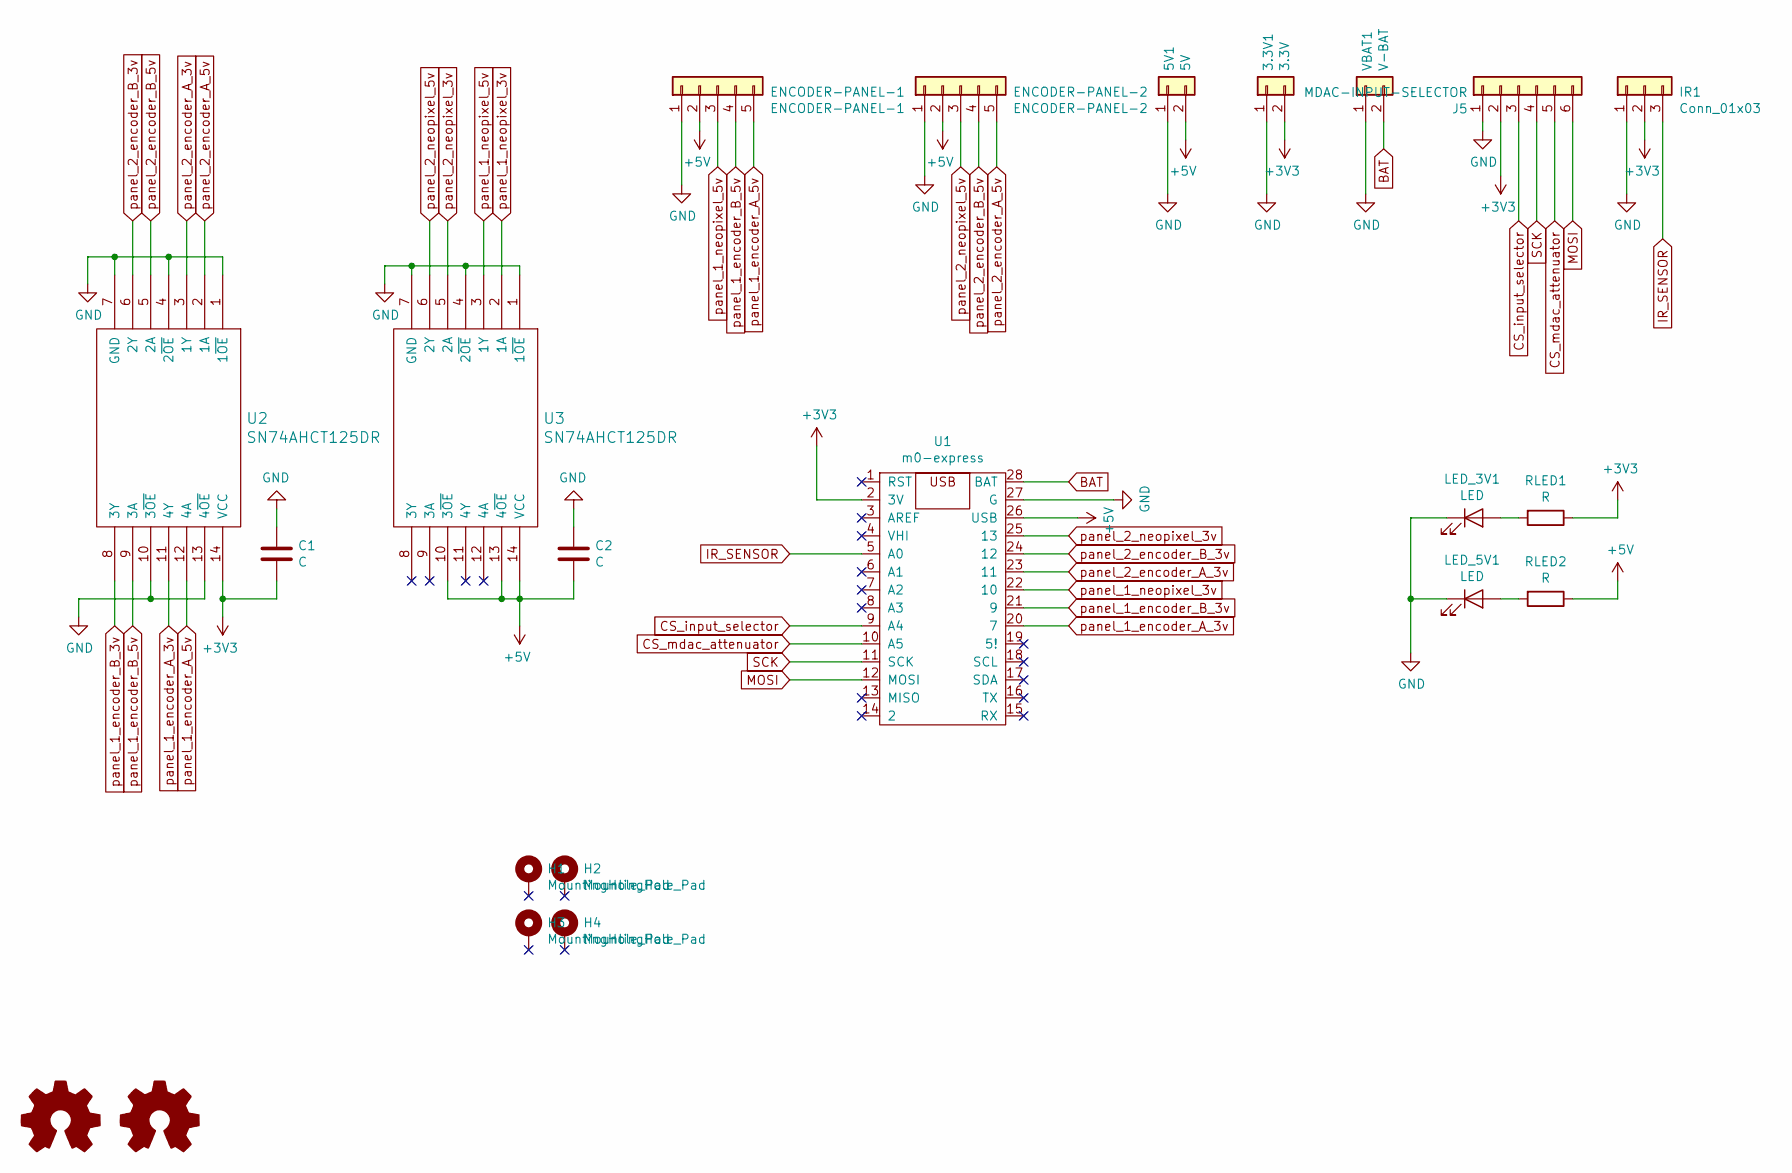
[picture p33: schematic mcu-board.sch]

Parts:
3.3V1: 3.3V; Molex_KK-254_AE-6410-02A_1x02_P2.54mm_Vertical
5V1: 5V; Molex_KK-254_AE-6410-02A_1x02_P2.54mm_Vertical
C1, C2: C; C_1206_3216Metric_Pad1.42x1.75mm_HandSolder
ENCODER-PANEL-1: ENCODER-PANEL-1; Molex_KK-254_AE-6410-05A_1x05_P2.54mm_Vertical
ENCODER-PANEL-2: ENCODER-PANEL-2; Molex_KK-254_AE-6410-05A_1x05_P2.54mm_Vertical
H1, H2, H3, H4: MountingHole_Pad; MountingHole_3.2mm_M3_Pad
IR1: Conn_01x03; Molex_KK-254_AE-6410-03A_1x03_P2.54mm_Vertical
J5: MDAC-INPUT-SELECTOR; Molex_KK-254_AE-6410-06A_1x06_P2.54mm_Vertical
LED_3V1, LED_5V1: LED; LED_1206_3216Metric_Pad1.42x1.75mm_HandSolder
LOGO1, LOGO2: Logo_Open_Hardware_Small; OSHW-Logo2_14.6x12mm_SilkScreen
RLED1, RLED2: R; R_1206_3216Metric_Pad1.42x1.75mm_HandSolder
U1: m0-express
U2, U3: SN74AHCT125DR; SOIC-14_3.9x8.7mm_P1.27mm
VBAT1: V-BAT; Molex_KK-254_AE-6410-02A_1x02_P2.54mm_Vertical

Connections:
+3V3: 3.3V1.2, C1.2, IR1.2, J5.2, RLED1.1, U1.2 (3V), U2.14 (VCC)
+5V: 5V1.2, C2.2, ENCODER-PANEL-1.2, ENCODER-PANEL-2.2, RLED2.1, U1.26 (USB), U3.10 (3~OE), U3.13 (4~OE), U3.14 (VCC)
BAT: U1.28 (BAT), VBAT1.2
CS_input_selector: J5.3, U1.9 (A4)
CS_mdac_attenuator: J5.5, U1.10 (A5)
GND: 3.3V1.1, 5V1.1, C1.1, C2.1, ENCODER-PANEL-1.1, ENCODER-PANEL-2.1, IR1.1, J5.1, LED_3V1.1 (K), LED_5V1.1 (K), U1.27 (G), U2.1 (1~OE), U2.4 (2~OE), U2.7 (GND), U2.10 (3~OE), U2.13 (4~OE), U3.1 (1~OE), U3.4 (2~OE), U3.7 (GND), VBAT1.1
IR_SENSOR: IR1.3, U1.5 (A0)
MOSI: J5.6, U1.12 (MOSI)
unnamed: LED_3V1.2 (A), RLED1.2
unnamed: LED_5V1.2 (A), RLED2.2
SCK: J5.4, U1.11 (SCK)
panel_1_encoder_A_3v: U1.20 (7), U2.11 (4Y)
panel_1_encoder_A_5v: ENCODER-PANEL-1.5, U2.12 (4A)
panel_1_encoder_B_3v: U1.21 (9), U2.8 (3Y)
panel_1_encoder_B_5v: ENCODER-PANEL-1.4, U2.9 (3A)
panel_1_neopixel_3v: U1.22 (10), U3.2 (1A)
panel_1_neopixel_5v: ENCODER-PANEL-1.3, U3.3 (1Y)
panel_2_encoder_A_3v: U1.23 (11), U2.3 (1Y)
panel_2_encoder_A_5v: ENCODER-PANEL-2.5, U2.2 (1A)
panel_2_encoder_B_3v: U1.24 (12), U2.6 (2Y)
panel_2_encoder_B_5v: ENCODER-PANEL-2.4, U2.5 (2A)
panel_2_neopixel_3v: U1.25 (13), U3.5 (2A)
panel_2_neopixel_5v: ENCODER-PANEL-2.3, U3.6 (2Y)

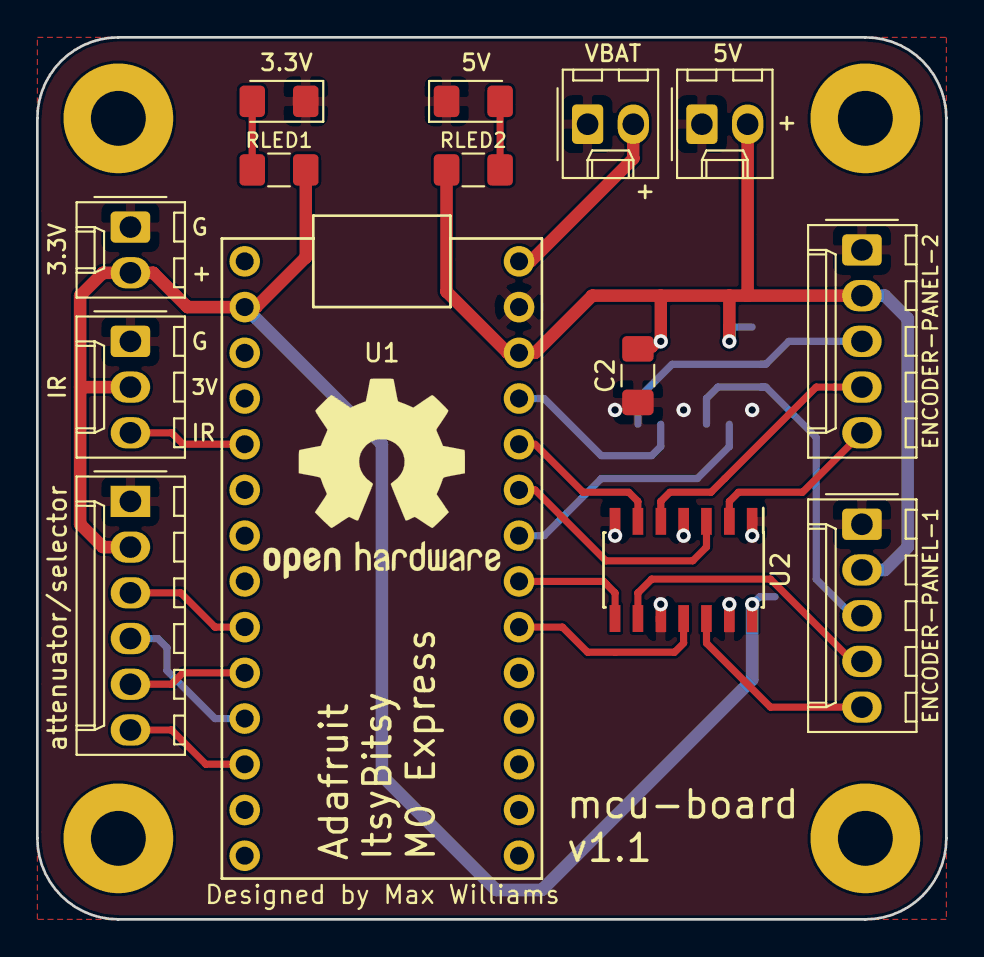
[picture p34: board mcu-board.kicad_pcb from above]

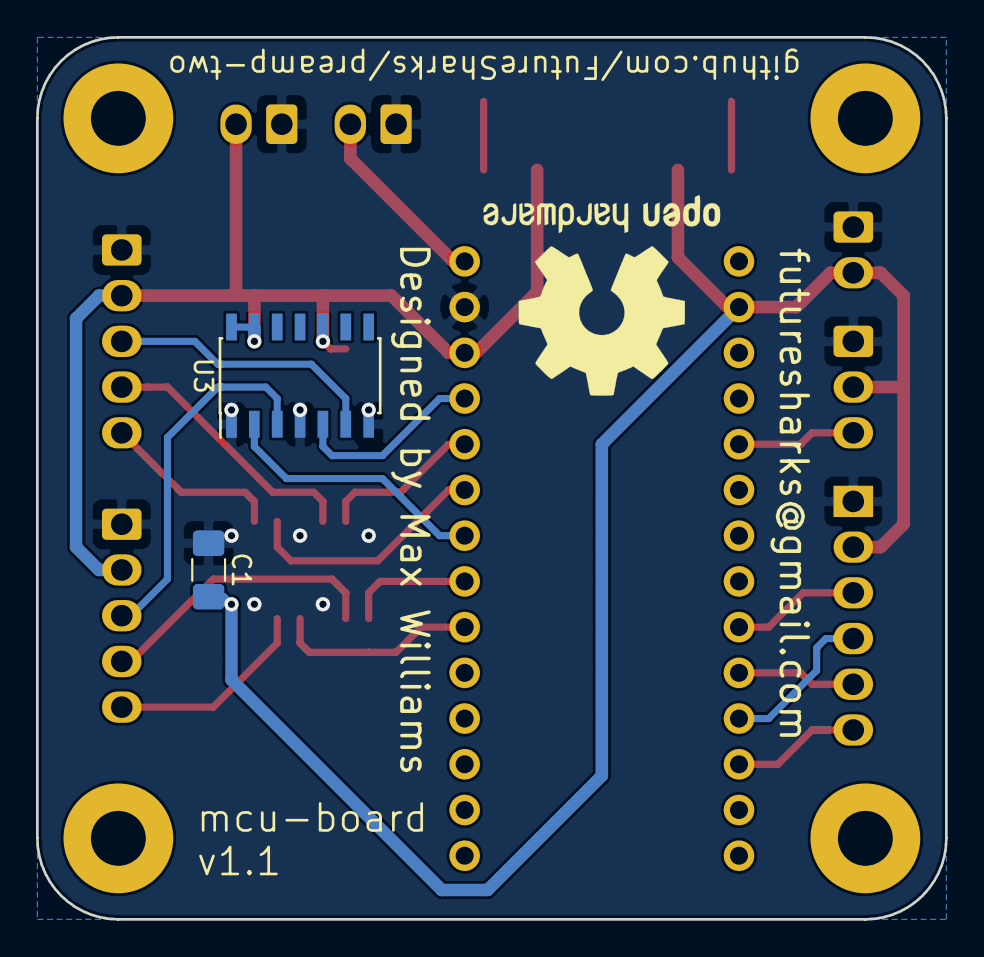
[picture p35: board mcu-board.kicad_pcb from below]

Board: 2 copper layers, 50.5 x 49.0 mm, 22 parts (3 on the bottom side), 23 nets.

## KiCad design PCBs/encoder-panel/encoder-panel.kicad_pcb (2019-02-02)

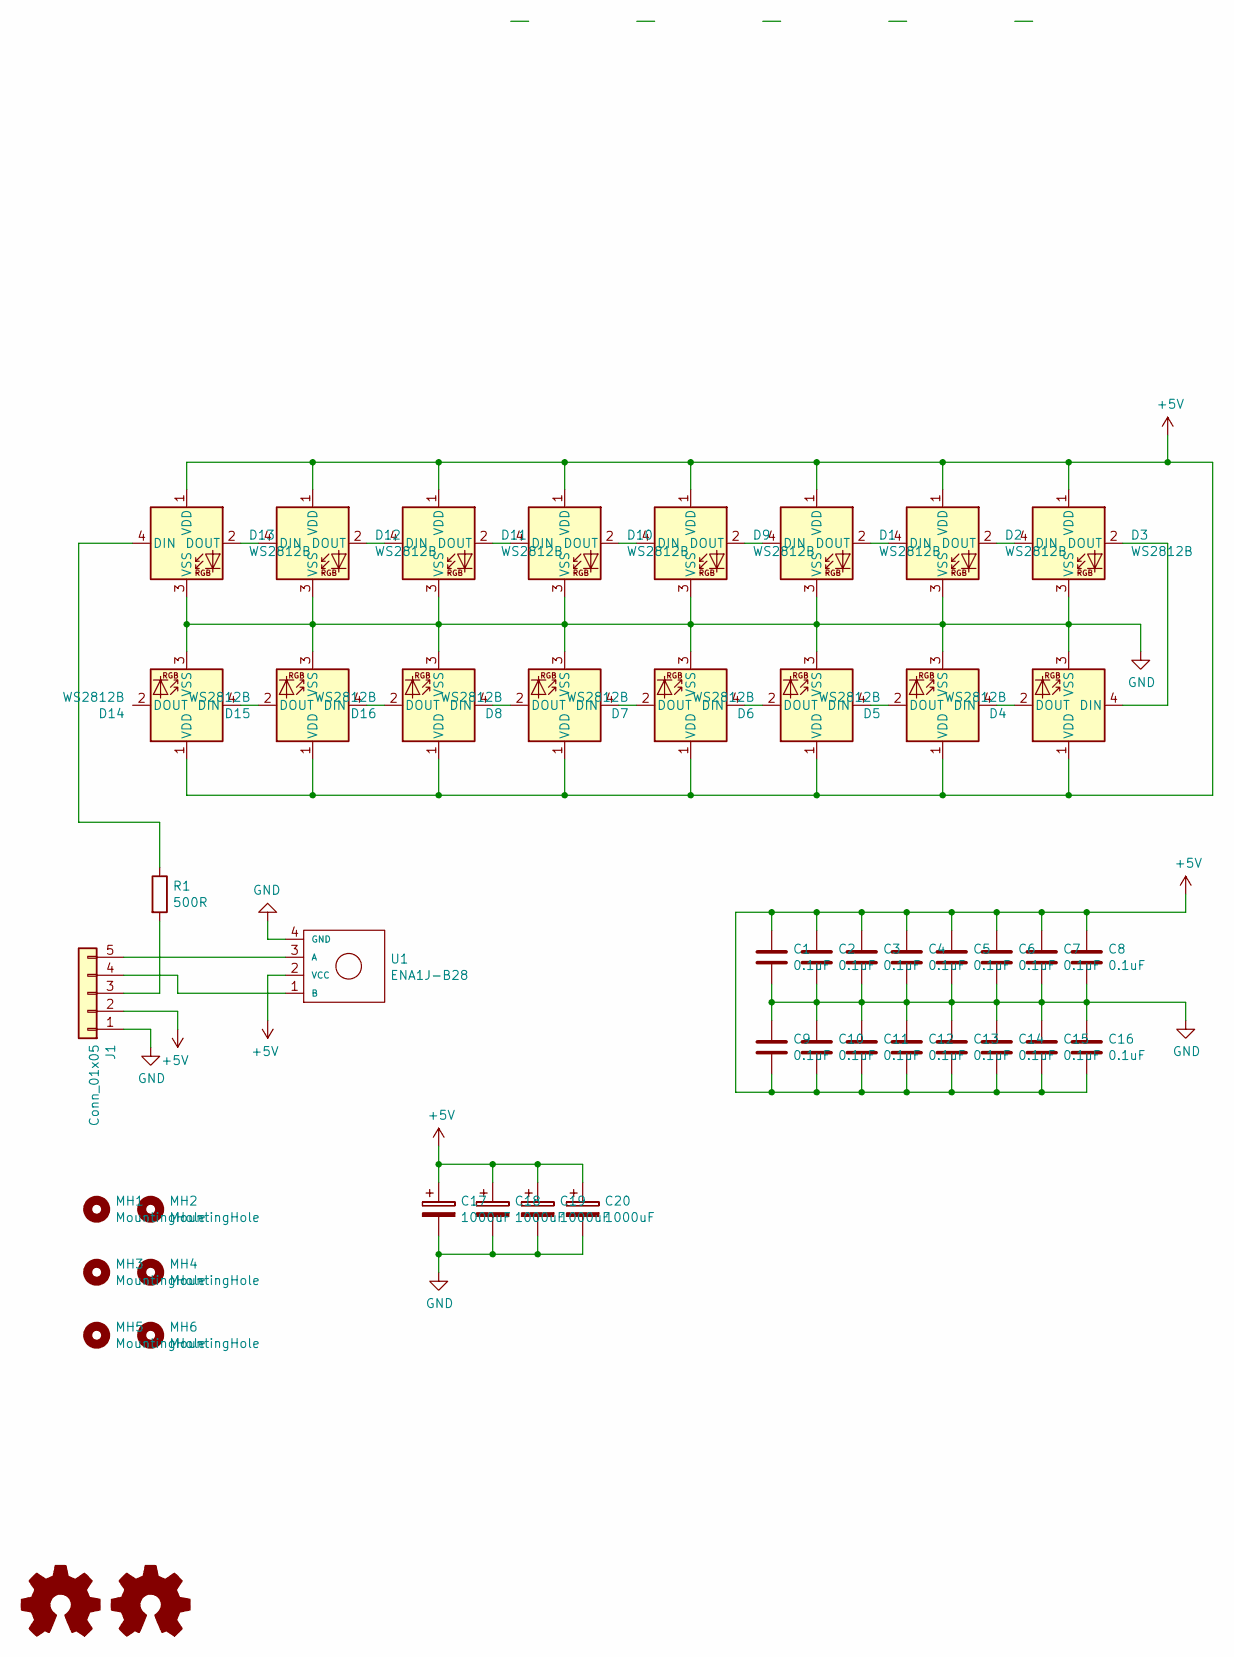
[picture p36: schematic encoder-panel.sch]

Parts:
C1, C2, C3, C4, C5, C6, C7, C8, C9, C10, C11, C12, C13, C14, C15, C16: 0.1uF; C_1206_3216Metric_Pad1.42x1.75mm_HandSolder
C17, C18: 1000uF; CP_Elec_8x5.4
C19, C20: 1000uF; CP_Radial_D8.0mm_P5.00mm
D1, D2, D3, D4, D5, D6, D7, D8, D9, D10, D11, D12, D13, D14, D15, D16: WS2812B; LED_WS2812B_PLCC4_5.0x5.0mm_P3.2mm
J1: Conn_01x05; Molex_KK-254_AE-6410-05A_1x05_P2.54mm_Vertical
LOGO1, LOGO2: Logo_Open_Hardware_Small; OSHW-Logo2_9.8x8mm_SilkScreen
MH1, MH2, MH3, MH4, MH5, MH6: MountingHole; MountingHole_3.2mm_M3_ISO14580
R1: 500R; R_1206_3216Metric_Pad1.42x1.75mm_HandSolder
U1: ENA1J-B28; ENA1J-B28-L00128L

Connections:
+5V: C1.1, C2.1, C3.1, C4.1, C5.1, C6.1, C7.1, C8.1, C9.2, C10.2, C11.2, C12.2, C13.2, C14.2, C15.2, C16.2, C17.1, C18.1, C19.1, C20.1, D1.1 (VDD), D2.1 (VDD), D3.1 (VDD), D4.1 (VDD), D5.1 (VDD), D6.1 (VDD), D7.1 (VDD), D8.1 (VDD), D9.1 (VDD), D10.1 (VDD), D11.1 (VDD), D12.1 (VDD), D13.1 (VDD), D14.1 (VDD), D15.1 (VDD), D16.1 (VDD), J1.2, U1.2 (VCC)
GND: C1.2, C2.2, C3.2, C4.2, C5.2, C6.2, C7.2, C8.2, C9.1, C10.1, C11.1, C12.1, C13.1, C14.1, C15.1, C16.1, C17.2, C18.2, C19.2, C20.2, D1.3 (VSS), D2.3 (VSS), D3.3 (VSS), D4.3 (VSS), D5.3 (VSS), D6.3 (VSS), D7.3 (VSS), D8.3 (VSS), D9.3 (VSS), D10.3 (VSS), D11.3 (VSS), D12.3 (VSS), D13.3 (VSS), D14.3 (VSS), D15.3 (VSS), D16.3 (VSS), J1.1, U1.4 (GND)
unnamed: D1.2 (DOUT), D2.4 (DIN)
unnamed: D1.4 (DIN), D9.2 (DOUT)
unnamed: D2.2 (DOUT), D3.4 (DIN)
unnamed: D3.2 (DOUT), D4.4 (DIN)
unnamed: D4.2 (DOUT), D5.4 (DIN)
unnamed: D5.2 (DOUT), D6.4 (DIN)
unnamed: D6.2 (DOUT), D7.4 (DIN)
unnamed: D7.2 (DOUT), D8.4 (DIN)
unnamed: D9.4 (DIN), D10.2 (DOUT)
unnamed: D10.4 (DIN), D11.2 (DOUT)
unnamed: D11.4 (DIN), D12.2 (DOUT)
unnamed: D12.4 (DIN), D13.2 (DOUT)
unnamed: D13.4 (DIN), R1.1
unnamed: D14.4 (DIN), D15.2 (DOUT)
unnamed: D15.4 (DIN), D16.2 (DOUT)
unnamed: D8.2 (DOUT), D16.4 (DIN)
unnamed: J1.3, R1.2
unnamed: J1.4, U1.1 (B)
unnamed: J1.5, U1.3 (A)

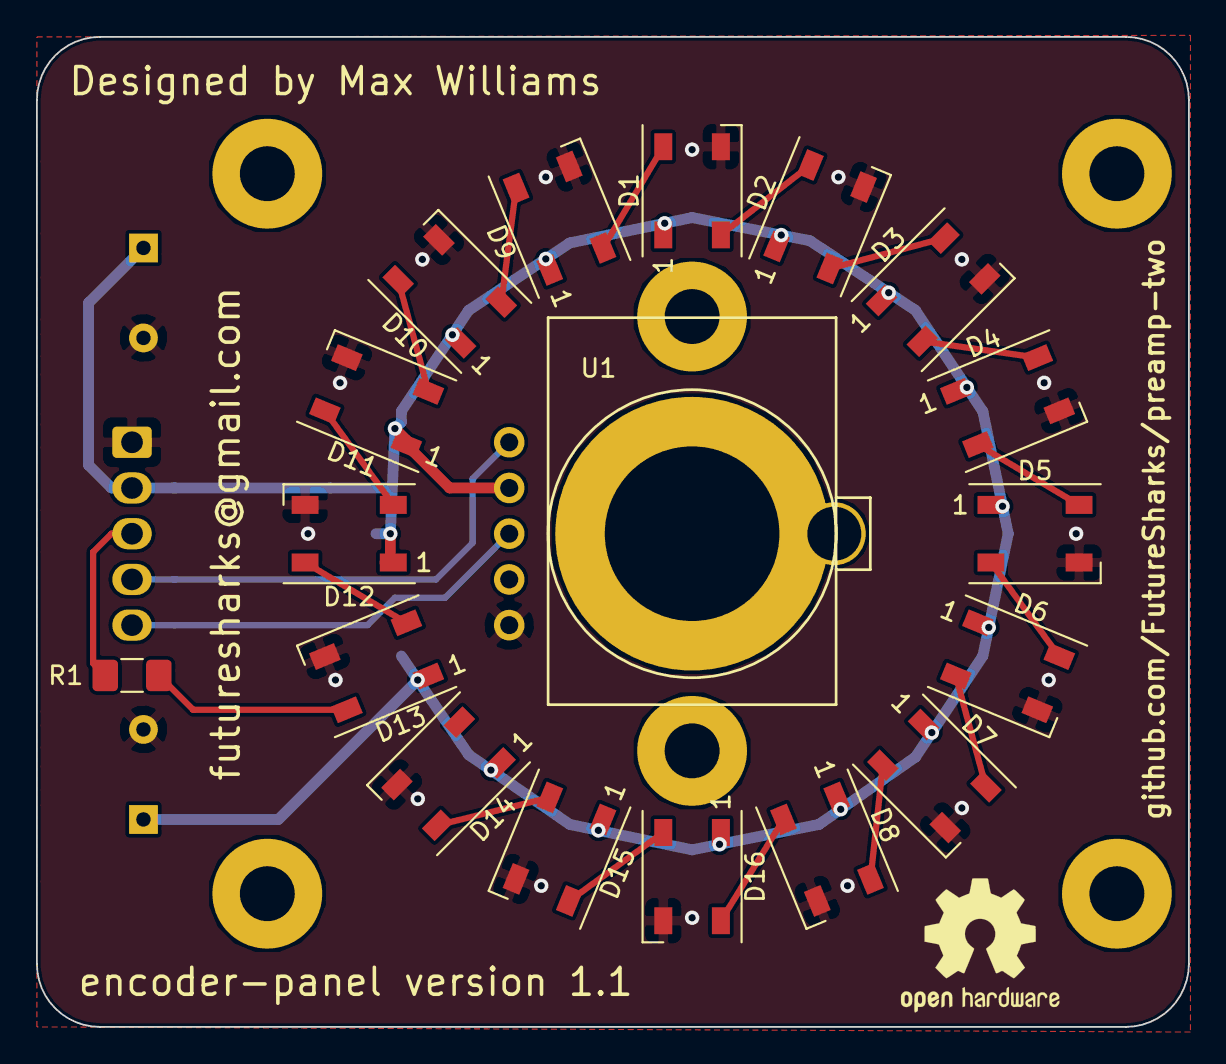
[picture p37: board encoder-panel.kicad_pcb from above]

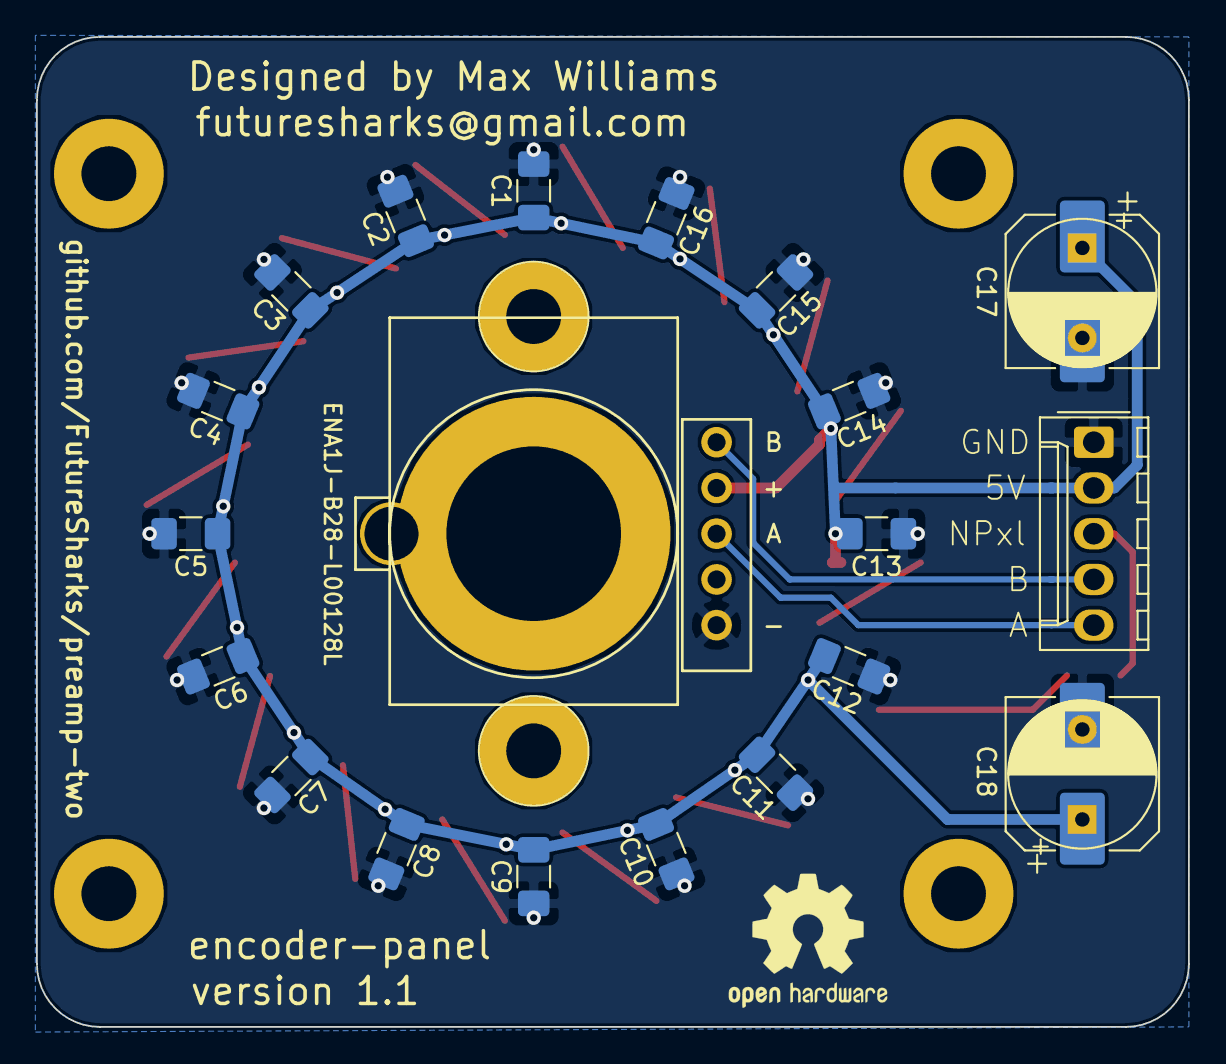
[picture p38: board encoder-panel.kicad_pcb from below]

Board: 2 copper layers, 64.0 x 55.0 mm, 47 parts (22 on the bottom side), 21 nets.

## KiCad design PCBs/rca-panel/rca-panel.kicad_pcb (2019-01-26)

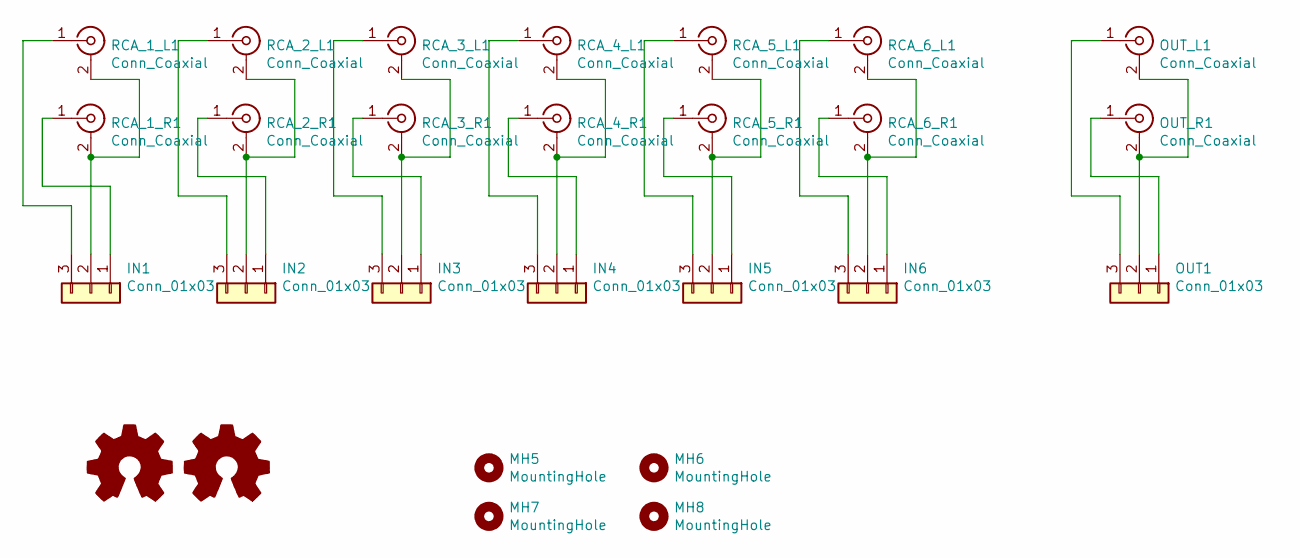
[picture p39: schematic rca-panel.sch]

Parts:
IN1, IN2, IN3, IN4, IN5, IN6: Conn_01x03; PinHeader_1x03_P2.54mm_Vertical
LOGO1, LOGO2: Logo_Open_Hardware_Small; OSHW-Logo2_7.3x6mm_SilkScreen
MH5, MH6, MH7, MH8: MountingHole; MountingHole_3.2mm_M3_ISO7380
OUT1: Conn_01x03; PinHeader_1x03_P2.54mm_Vertical
OUT_L1: Conn_Coaxial; cmc-805-new
OUT_R1: Conn_Coaxial; cmc-805-new
RCA_1_L1, RCA_1_R1, RCA_2_L1, RCA_2_R1, RCA_3_L1, RCA_3_R1, RCA_4_L1, RCA_4_R1, RCA_5_L1, RCA_5_R1, RCA_6_L1, RCA_6_R1: Conn_Coaxial; cmc-805-new

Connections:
unnamed: IN1.1, RCA_1_R1.1 (In)
unnamed: IN1.2, RCA_1_L1.2 (Ext), RCA_1_R1.2 (Ext)
unnamed: IN1.3, RCA_1_L1.1 (In)
unnamed: IN2.1, RCA_2_R1.1 (In)
unnamed: IN2.2, RCA_2_L1.2 (Ext), RCA_2_R1.2 (Ext)
unnamed: IN2.3, RCA_2_L1.1 (In)
unnamed: IN3.1, RCA_3_R1.1 (In)
unnamed: IN3.2, RCA_3_L1.2 (Ext), RCA_3_R1.2 (Ext)
unnamed: IN3.3, RCA_3_L1.1 (In)
unnamed: IN4.1, RCA_4_R1.1 (In)
unnamed: IN4.2, RCA_4_L1.2 (Ext), RCA_4_R1.2 (Ext)
unnamed: IN4.3, RCA_4_L1.1 (In)
unnamed: IN5.1, RCA_5_R1.1 (In)
unnamed: IN5.2, RCA_5_L1.2 (Ext), RCA_5_R1.2 (Ext)
unnamed: IN5.3, RCA_5_L1.1 (In)
unnamed: IN6.1, RCA_6_R1.1 (In)
unnamed: IN6.2, RCA_6_L1.2 (Ext), RCA_6_R1.2 (Ext)
unnamed: IN6.3, RCA_6_L1.1 (In)
unnamed: OUT1.1, OUT_R1.1 (In)
unnamed: OUT1.2, OUT_L1.2 (Ext), OUT_R1.2 (Ext)
unnamed: OUT1.3, OUT_L1.1 (In)

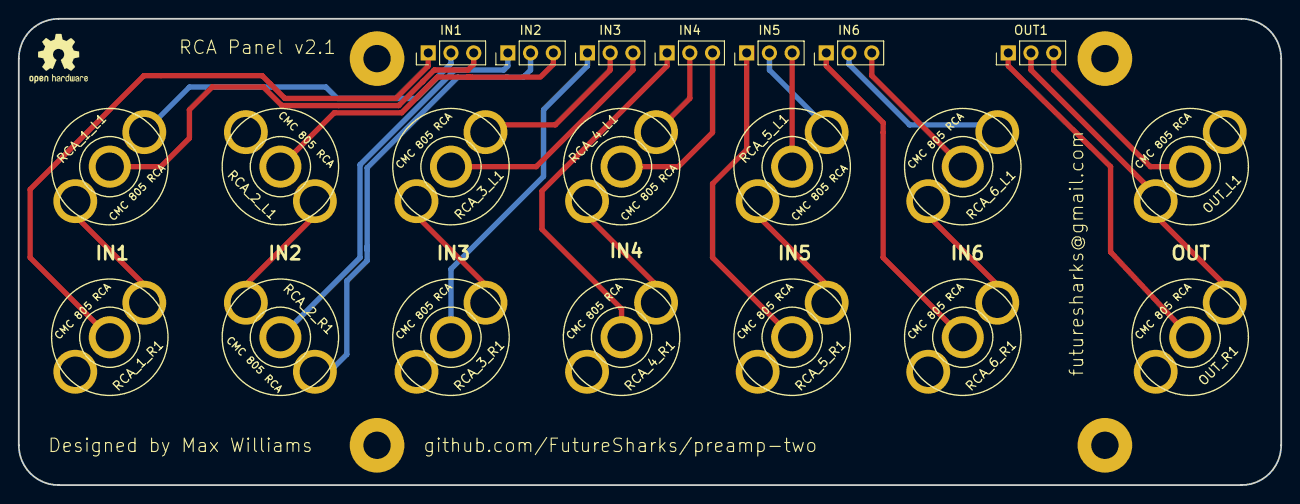
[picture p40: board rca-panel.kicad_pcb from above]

Board: 2 copper layers, 141.0 x 52.1 mm, 27 parts (0 on the bottom side), 21 nets.

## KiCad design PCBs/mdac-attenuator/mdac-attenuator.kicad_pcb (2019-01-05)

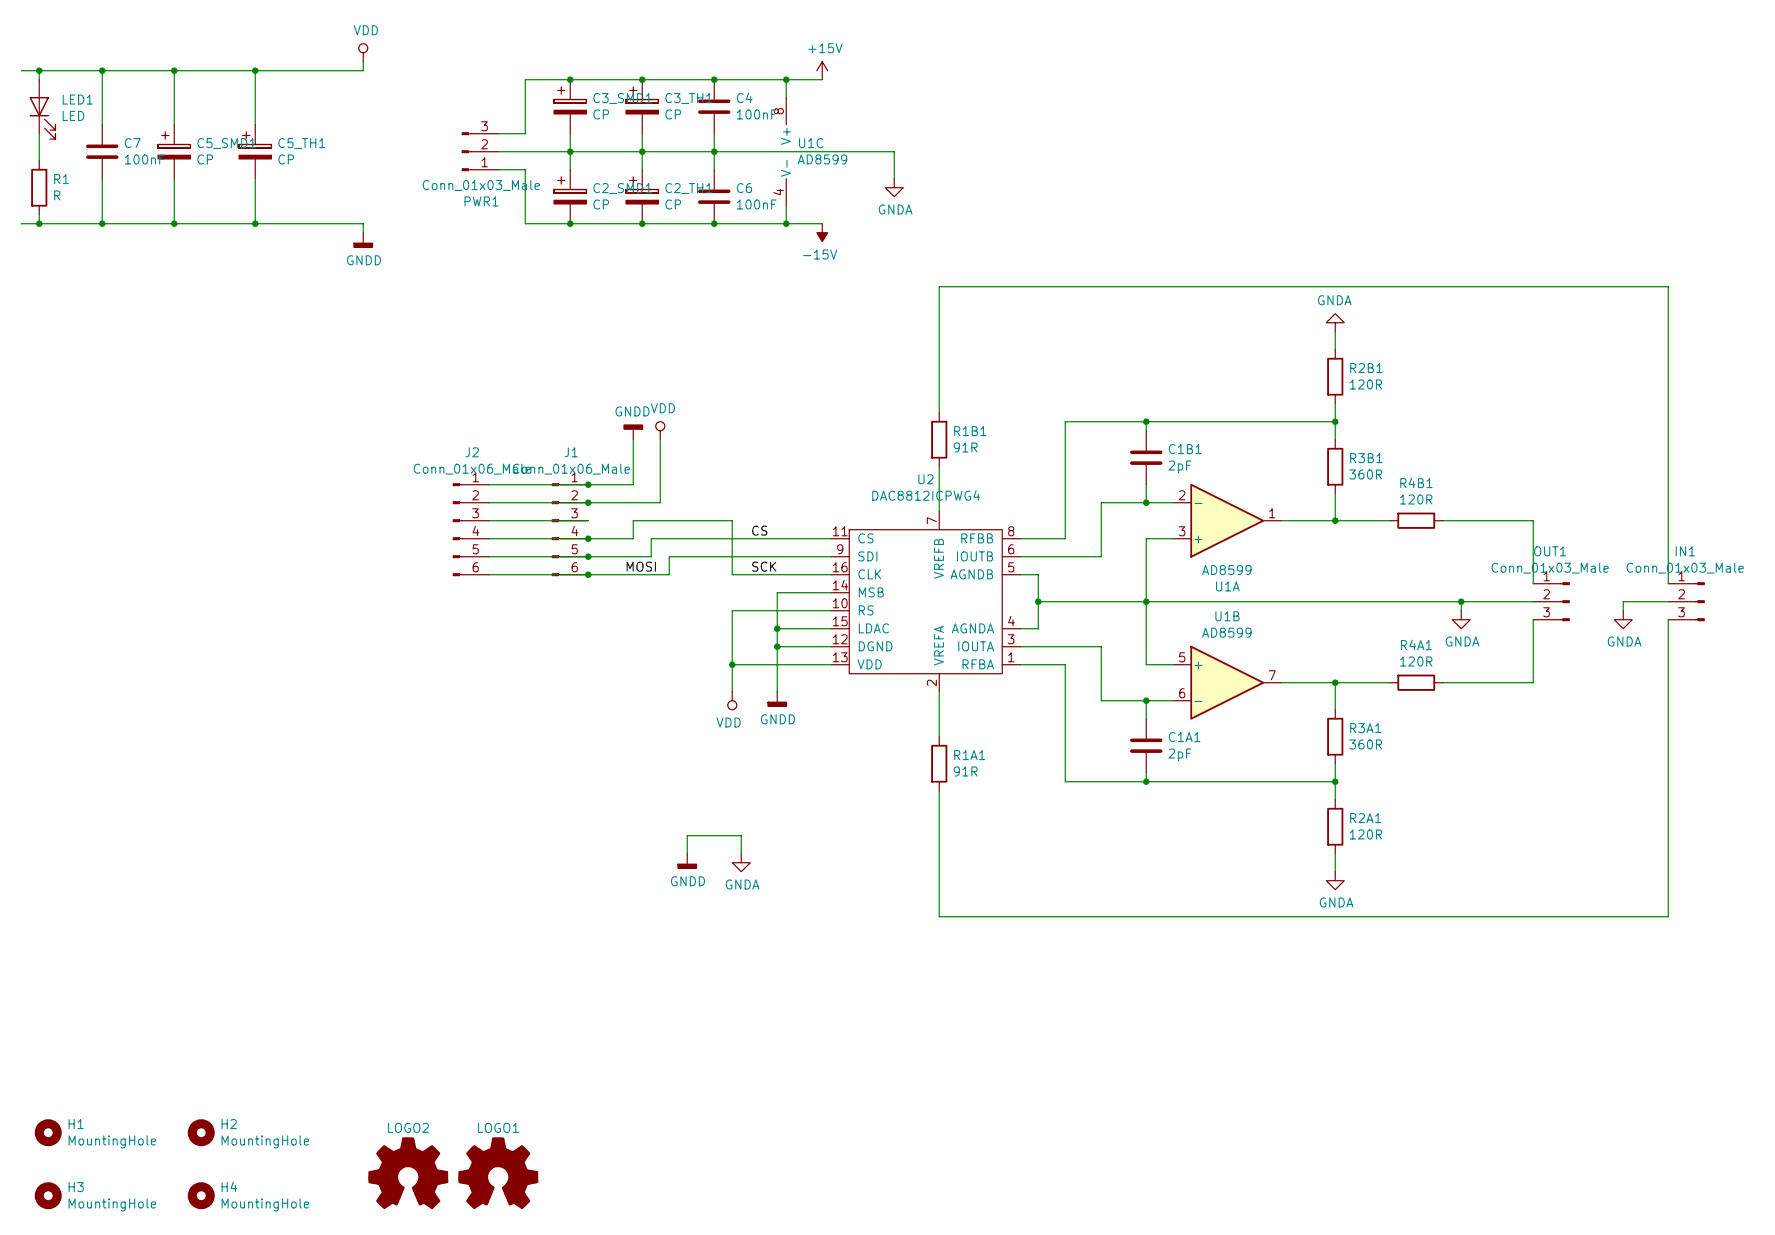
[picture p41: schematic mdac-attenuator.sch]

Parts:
C1A1, C1B1: 2pF; C_0805_2012Metric_Pad1.15x1.40mm_HandSolder
C2_SMD1, C3_SMD1, C5_SMD1: CP; CP_Elec_8x10
C2_TH1, C3_TH1, C5_TH1: CP; CP_Radial_D10.0mm_P5.00mm
C4, C6, C7: 100nF; C_1206_3216Metric_Pad1.42x1.75mm_HandSolder
H1, H2, H3, H4: MountingHole; MountingHole_3.2mm_M3_DIN965
IN1: Conn_01x03_Male; Molex_KK-254_AE-6410-03A_1x03_P2.54mm_Vertical
J1: Conn_01x06_Male; Molex_KK-254_AE-6410-06A_1x06_P2.54mm_Vertical
J2: Conn_01x06_Male; PinHeader_1x06_P2.54mm_Vertical
LED1: LED; LED_1206_3216Metric
LOGO1, LOGO2: Logo_Open_Hardware_Small; OSHW-Logo_7.5x8mm_SilkScreen
OUT1: Conn_01x03_Male; Molex_KK-254_AE-6410-03A_1x03_P2.54mm_Vertical
PWR1: Conn_01x03_Male; Molex_KK-254_AE-6410-03A_1x03_P2.54mm_Vertical
R1: R; R_1206_3216Metric_Pad1.42x1.75mm_HandSolder
R1A1, R1B1: 91R; R_1206_3216Metric_Pad1.42x1.75mm_HandSolder
R2A1, R2B1, R4A1, R4B1: 120R; R_1206_3216Metric_Pad1.42x1.75mm_HandSolder
R3A1, R3B1: 360R; R_1206_3216Metric_Pad1.42x1.75mm_HandSolder
U1: AD8599; SOIC-8_3.9x4.9mm_P1.27mm
U2: DAC8812ICPWG4; TSSOP-16_4.4x5mm_P0.65mm

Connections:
+15V: C3_SMD1.1, C3_TH1.1, C4.1, PWR1.3, U1.8 (V+)
-15V: C2_SMD1.2, C2_TH1.2, C6.2, PWR1.1, U1.4 (V-)
/CS: J1.5, J2.5, U2.11 (CS)
/MOSI: J1.6, J2.6, U2.9 (SDI)
/SCK: J1.4, J2.4, U2.16 (CLK)
GNDA: C2_SMD1.1, C2_TH1.1, C3_SMD1.2, C3_TH1.2, C4.2, C5_SMD1.2, C5_TH1.2, C6.1, C7.2, IN1.2, J1.1, J2.1, OUT1.2, PWR1.2, R1.2, R2A1.2, R2B1.1, U1.3 (+), U1.5 (+), U2.4 (AGNDA), U2.5 (AGNDB), U2.12 (DGND), U2.14 (MSB), U2.15 (LDAC)
unnamed: C1A1.1, U1.6 (-), U2.3 (IOUTA)
unnamed: C1A1.2, R2A1.1, R3A1.2, U2.1 (RFBA)
unnamed: C1B1.1, R2B1.2, R3B1.1, U2.8 (RFBB)
unnamed: C1B1.2, U1.2 (-), U2.6 (IOUTB)
unnamed: IN1.1, R1B1.1
unnamed: IN1.3, R1A1.2
unnamed: J1.3, J2.3
unnamed: LED1.1 (K), R1.1
unnamed: OUT1.1, R4B1.1
unnamed: OUT1.3, R4A1.1
unnamed: R1A1.1, U2.2 (VREFA)
unnamed: R1B1.2, U2.7 (VREFB)
unnamed: R3A1.1, R4A1.2, U1.7
unnamed: R3B1.2, R4B1.2, U1.1
VDD: C5_SMD1.1, C5_TH1.1, C7.1, J1.2, J2.2, LED1.2 (A), U2.10 (RS), U2.13 (VDD)

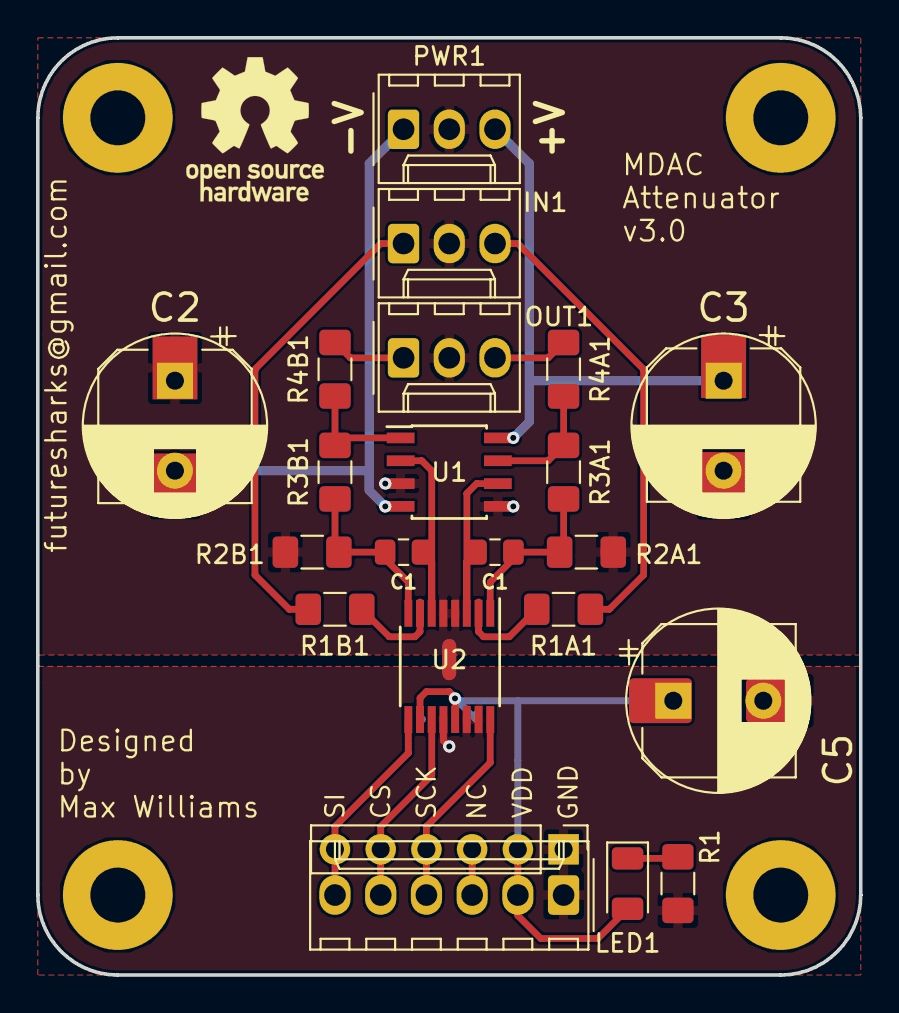
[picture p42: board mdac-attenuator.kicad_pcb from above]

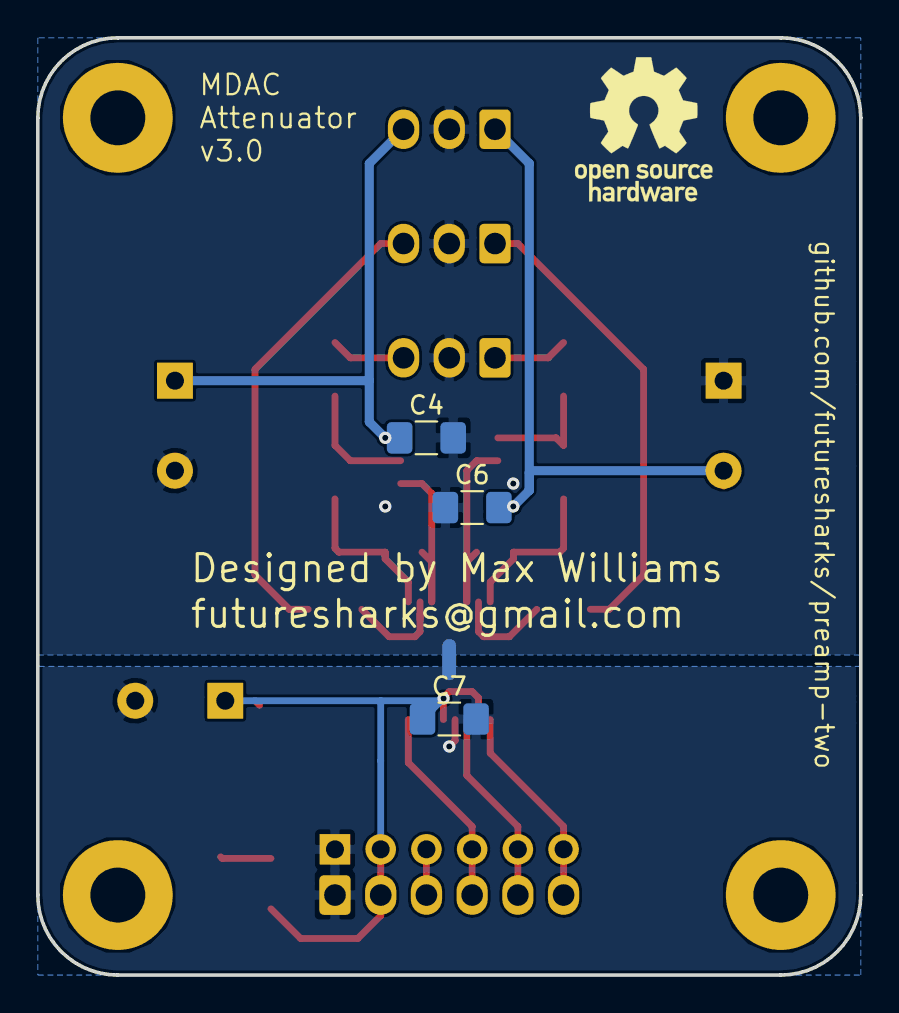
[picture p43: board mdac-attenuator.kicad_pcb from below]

Board: 2 copper layers, 45.7 x 52.1 mm, 34 parts (4 on the bottom side), 21 nets.

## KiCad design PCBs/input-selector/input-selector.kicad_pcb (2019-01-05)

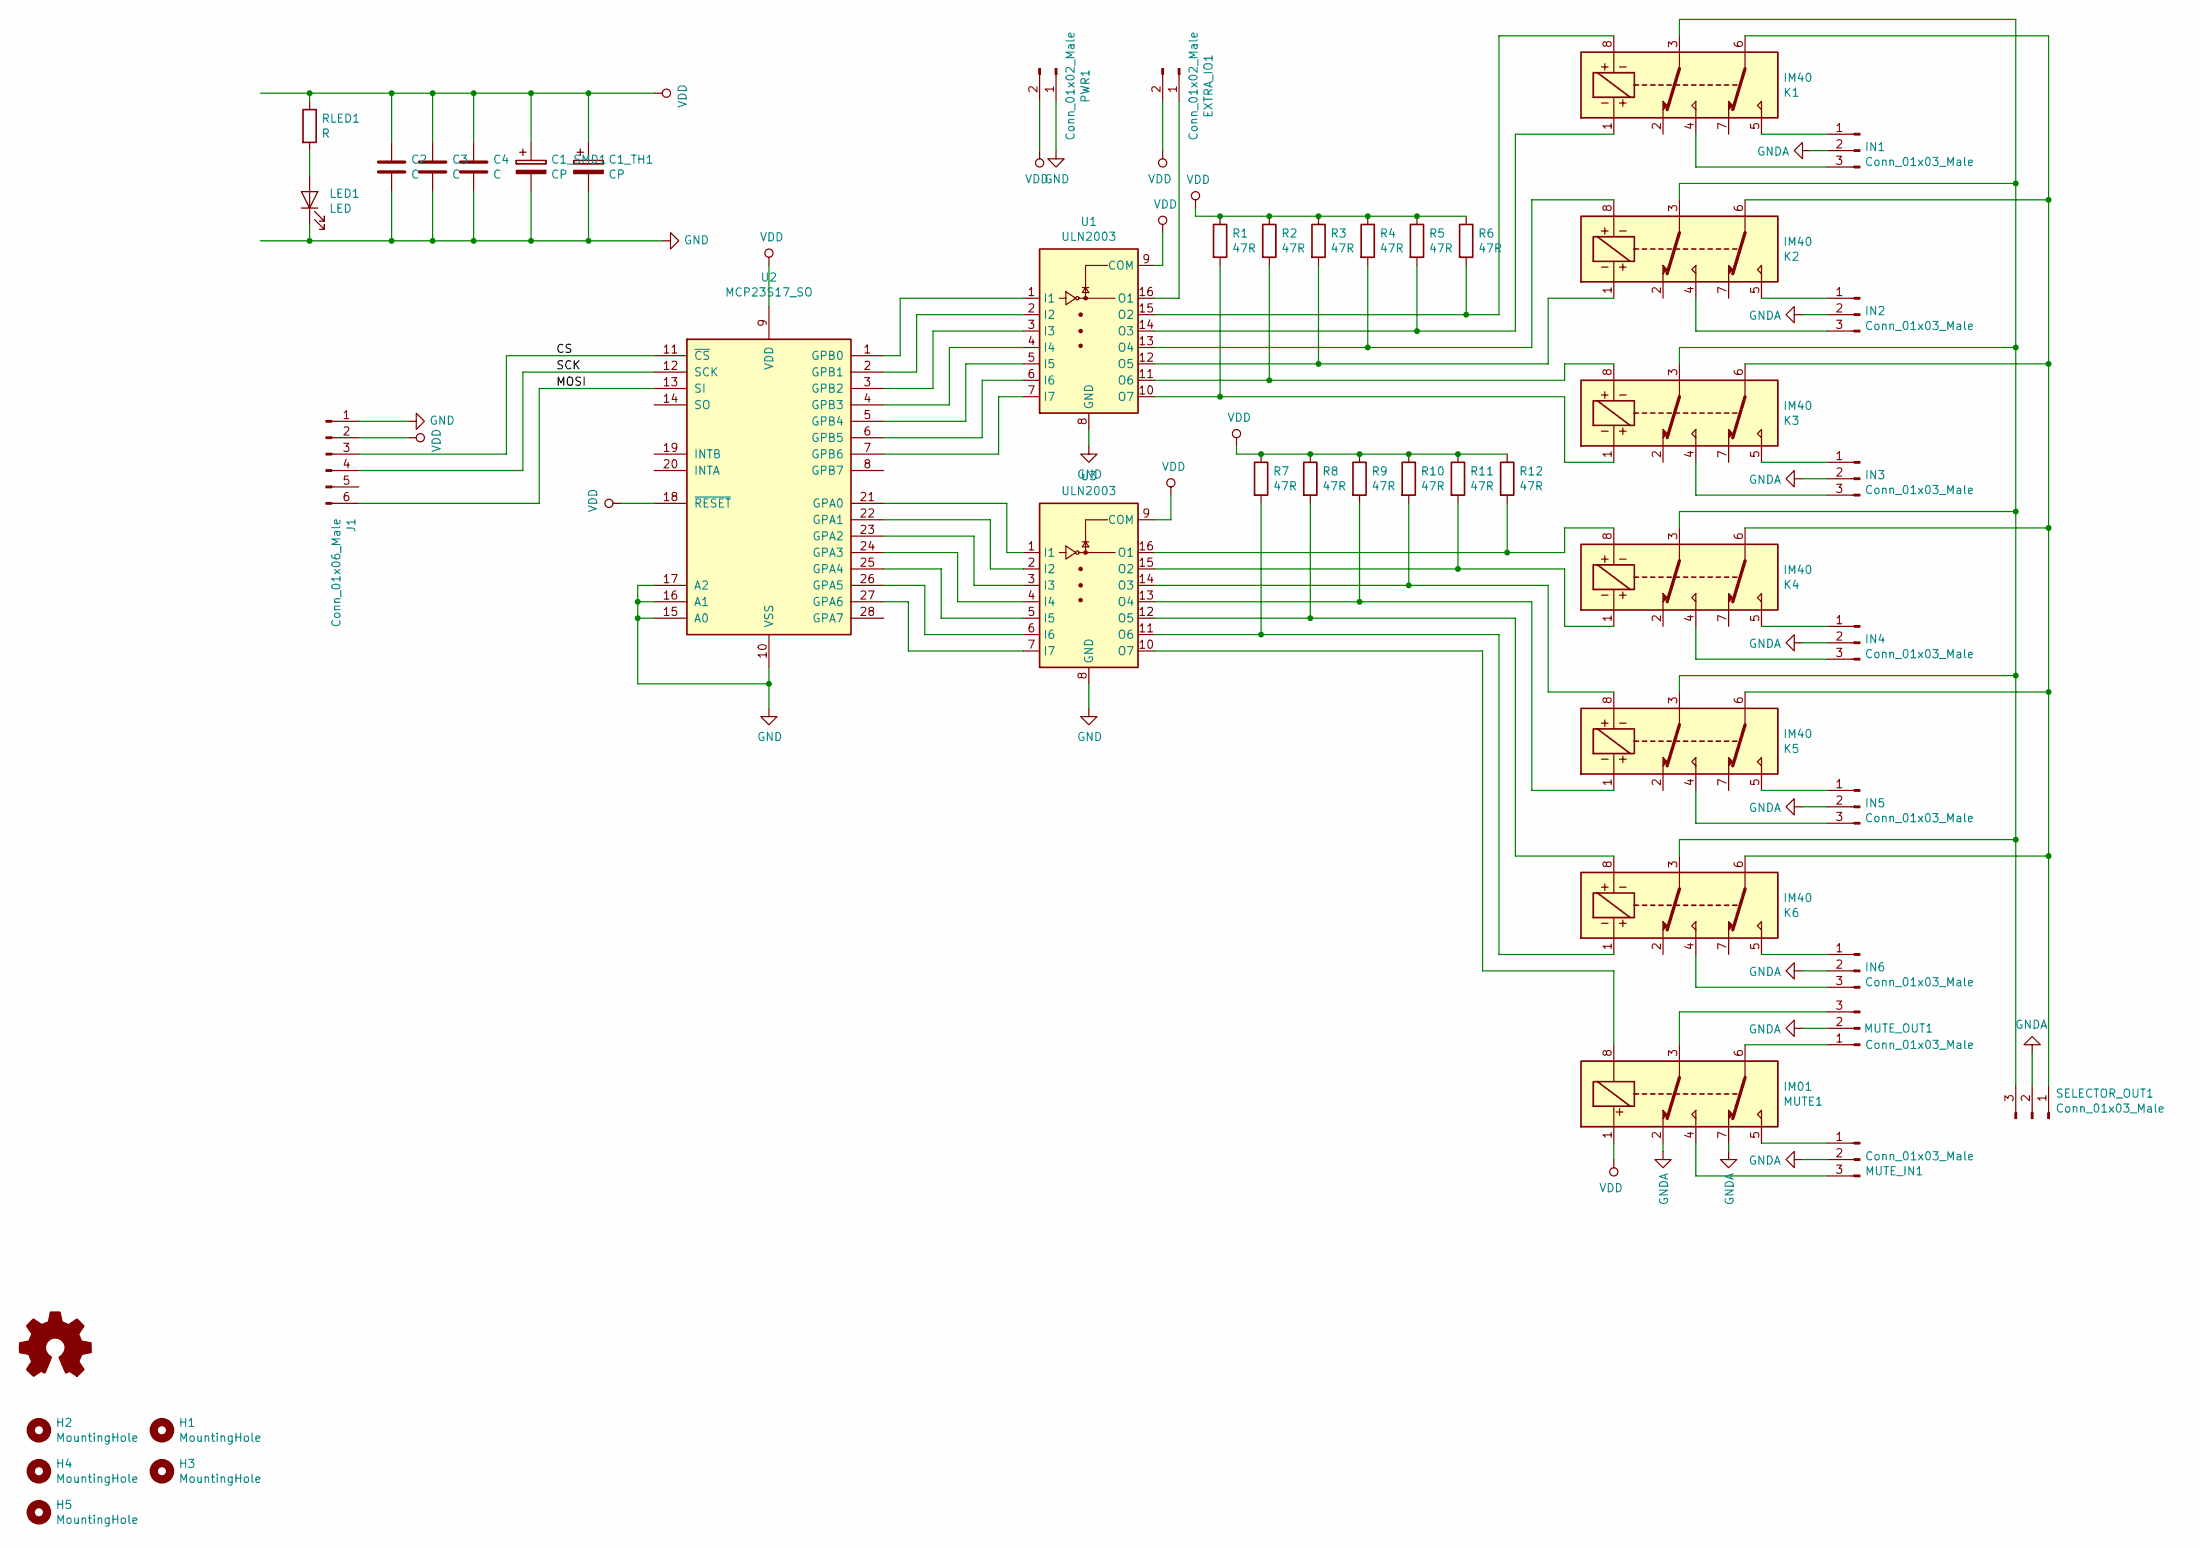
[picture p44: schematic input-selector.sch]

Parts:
C1_SMD1: CP; CP_Elec_10x7.9
C1_TH1: CP; CP_Radial_D10.0mm_P5.00mm
C2, C3, C4: C; C_1206_3216Metric_Pad1.42x1.75mm_HandSolder
EXTRA_IO1: Conn_01x02_Male; Molex_KK-254_AE-6410-02A_1x02_P2.54mm_Vertical
H1, H2, H3, H4, H5: MountingHole; MountingHole_3.2mm_M3_DIN965
IN1, IN2, IN3, IN4, IN5, IN6: Conn_01x03_Male; Molex_KK-254_AE-6410-03A_1x03_P2.54mm_Vertical
J1: Conn_01x06_Male; Molex_KK-254_AE-6410-06A_1x06_P2.54mm_Vertical
K1, K2, K3, K4, K5, K6: IM40; g6j-2p-y
LED1: LED; LED_1206_3216Metric
MUTE1: IM01; g6j-2p-y
MUTE_IN1: Conn_01x03_Male; Molex_KK-254_AE-6410-03A_1x03_P2.54mm_Vertical
MUTE_OUT1: Conn_01x03_Male; Molex_KK-254_AE-6410-03A_1x03_P2.54mm_Vertical
PWR1: Conn_01x02_Male; Molex_KK-254_AE-6410-02A_1x02_P2.54mm_Vertical
R1, R2, R3, R4, R5, R6, R7, R8, R9, R10, R11, R12: 47R; R_1206_3216Metric_Pad1.42x1.75mm_HandSolder
RLED1: R; R_1206_3216Metric_Pad1.42x1.75mm_HandSolder
SELECTOR_OUT1: Conn_01x03_Male; Molex_KK-254_AE-6410-03A_1x03_P2.54mm_Vertical
U1, U3: ULN2003; SOIC-16_3.9x9.9mm_P1.27mm
U2: MCP23S17_SO; SOIC-28W_7.5x17.9mm_P1.27mm

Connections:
/CS: J1.3, U2.11 (~CS~)
/MOSI: J1.6, U2.13 (SI)
/SCK: J1.4, U2.12 (SCK)
GND: C1_SMD1.2, C1_TH1.2, C2.2, C3.2, C4.2, J1.1, LED1.1 (K), PWR1.1, U1.8 (GND), U2.10 (VSS), U2.15 (A0), U2.16 (A1), U2.17 (A2), U3.8 (GND)
GNDA: IN1.2, IN2.2, IN3.2, IN4.2, IN5.2, IN6.2, MUTE1.2, MUTE1.7, MUTE_IN1.2, MUTE_OUT1.2, SELECTOR_OUT1.2
unnamed: EXTRA_IO1.1, U1.16 (O1)
unnamed: IN1.1, K1.5
unnamed: IN1.3, K1.4
unnamed: IN2.1, K2.5
unnamed: IN2.3, K2.4
unnamed: IN3.1, K3.5
unnamed: IN3.3, K3.4
unnamed: IN4.1, K4.5
unnamed: IN4.3, K4.4
unnamed: IN5.1, K5.5
unnamed: IN5.3, K5.4
unnamed: IN6.1, K6.5
unnamed: IN6.3, K6.4
unnamed: K1.1, R5.2, U1.14 (O3)
unnamed: K1.3, K2.3, K3.3, K4.3, K5.3, K6.3, SELECTOR_OUT1.3
unnamed: K1.6, K2.6, K3.6, K4.6, K5.6, K6.6, SELECTOR_OUT1.1
unnamed: K1.8, R6.2, U1.15 (O2)
unnamed: K2.1, R3.2, U1.12 (O5)
unnamed: K2.8, R4.2, U1.13 (O4)
unnamed: K3.1, R1.2, U1.10 (O7)
unnamed: K3.8, R2.2, U1.11 (O6)
unnamed: K4.1, R11.2, U3.15 (O2)
unnamed: K4.8, R12.2, U3.16 (O1)
unnamed: K5.1, R9.2, U3.13 (O4)
unnamed: K5.8, R10.2, U3.14 (O3)
unnamed: K6.1, R7.2, U3.11 (O6)
unnamed: K6.8, R8.2, U3.12 (O5)
unnamed: LED1.2 (A), RLED1.2
unnamed: MUTE1.3, MUTE_OUT1.3
unnamed: MUTE1.4, MUTE_IN1.3
unnamed: MUTE1.5, MUTE_IN1.1
unnamed: MUTE1.6, MUTE_OUT1.1
unnamed: MUTE1.8, U3.10 (O7)
unnamed: U1.1 (I1), U2.1 (GPB0)
unnamed: U1.2 (I2), U2.2 (GPB1)
unnamed: U1.3 (I3), U2.3 (GPB2)
unnamed: U1.4 (I4), U2.4 (GPB3)
unnamed: U1.5 (I5), U2.5 (GPB4)
unnamed: U1.6 (I6), U2.6 (GPB5)
unnamed: U1.7 (I7), U2.7 (GPB6)
unnamed: U2.21 (GPA0), U3.1 (I1)
unnamed: U2.22 (GPA1), U3.2 (I2)
unnamed: U2.23 (GPA2), U3.3 (I3)
unnamed: U2.24 (GPA3), U3.4 (I4)
unnamed: U2.25 (GPA4), U3.5 (I5)
unnamed: U2.26 (GPA5), U3.6 (I6)
unnamed: U2.27 (GPA6), U3.7 (I7)
VDD: C1_SMD1.1, C1_TH1.1, C2.1, C3.1, C4.1, EXTRA_IO1.2, J1.2, MUTE1.1, PWR1.2, R1.1, R2.1, R3.1, R4.1, R5.1, R6.1, R7.1, R8.1, R9.1, R10.1, R11.1, R12.1, RLED1.1, U1.9 (COM), U2.9 (VDD), U2.18 (~RESET~), U3.9 (COM)



Board: 2 copper layers, 90.2 x 52.1 mm, 46 parts (15 on the bottom side), 53 nets.

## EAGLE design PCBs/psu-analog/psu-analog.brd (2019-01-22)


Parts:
AC: W237-02P; W237-132
B1, B2: DF02S; DFS
C1, C2: CPOL-EUE7.5-18; E7,5-18
C3A, C3B, C4A, C4B, C5, C6, C7, C8, C9, C10, C11, C12, C13, C14: C-EUC1206; C1206
C15, C16: CPOL-EUE5-13; E5-13
F1: GSH15
KK1, KK2: SK104-PAD
LED1, LED2: LEDSMT1206; 1206
R1A, R2B: 51.1K; R1206
R1B, R2A: 604K; R1206
RLED1, RLED2: R-EU_R1206; R1206
TR1: FL6-NO-HOLES
TR2: 5-7VA; 5_7VA-PC
TR3: EI42-2
U1, U2: TPS7A3301KC-OTHER-PACKAGE; 7TO-220-OTHER
U$1, U$2, U$3, U$4: M3_HOLE
X2: PWR Out; 22-23-2031

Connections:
AGND: B2.+, C2.+, C3B.1, C4A.2, C6.1, C8.1, C9.2, C10.1, C11.2, C12.1, C13.2, C14.1, C15.-, C16.+, R1A.1, R2B.2, RLED1.1, RLED2.2, U1.6 (OUT), U2.4 (GND), U2.5 (NC), X2.2
unnamed: TR1.P$2 (PRI1B), TR1.P$3 (PRI2A), TR2.4, TR2.5
unnamed: F1.2, TR1.P$1 (PRI1A), TR2.6, TR3.1
unnamed: AC.2, TR1.P$4 (PRI2B), TR2.3, TR3.5 (2)
unnamed: AC.1, F1.1
unnamed: LED2.A, RLED2.1
unnamed: LED1.C, RLED1.2
unnamed: C4A.1, R1A.2, R2A.1, U1.7 (FB)
unnamed: C3B.2, U2.2 (NR)
unnamed: C4B.1, R1B.2, R2B.1, U2.7 (FB)
unnamed: B1.AC2, TR1.P$6 (SEC1B), TR2.12, TR3.9 (5)
unnamed: B1.AC1, TR1.P$5 (SEC1A), TR2.11, TR3.10 (6)
unnamed: B2.AC2, TR1.P$8 (SEC2B), TR2.14, TR3.6 (3)
unnamed: C3A.2, U1.2 (NR)
unnamed: B2.AC1, TR1.P$7 (SEC2A), TR2.13, TR3.7 (4)
unnamed: C4B.2, C10.2, C12.2, C14.2, C16.-, LED2.C, R1B.1, U2.6 (OUT), X2.3
unnamed: B1.+, C1.+, C3A.1, C5.1, C7.1, C9.1, C11.1, C13.1, C15.+, LED1.A, R2A.2, U1.4 (GND), U1.5 (NC), X2.1
VIN+: B1.-, C1.-, C5.2, C7.2, U1.1 (EN), U1.3 (IN)
VIN-: B2.-, C2.-, C6.2, C8.2, U2.1 (EN), U2.3 (IN)



Board: 2 copper layers, 137.7 x 53.3 mm, 42 parts (2 on the bottom side), 19 nets.

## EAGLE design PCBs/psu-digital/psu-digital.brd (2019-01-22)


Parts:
AC: W237-02P; W237-132
B1: DF02S; DFS
C1: CPOL-EUE7.5-16; E7,5-16
C2, C3, C5: C-EUC1206; C1206
C4: CPOL-EUD; PANASONIC_D
DC_OUT1: 22-23-2021
F1: GSH15
IC1: LT1763; SOIC8
L1: 1210
L2: 1206
LED: LEDCHIPLED_1206; CHIPLED_1206
LOGO1: OSHW_LOGO_FILLX0200-NT; OSHW_FILLX200_NOTEXT
R1: R-EU_R1206; R1206
R2: R-EU_R1210; R1210
TR1: FL2/4/6/8-NO-HOLES

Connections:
GND: B1.-, C1.-, C2.2, C4.-, C5.2, DC_OUT1.2, IC1.3 (GND), IC1.6 (GND), IC1.7 (GND), R1.1
unnamed: TR1.P$2 (PRI1B), TR1.P$3 (PRI2A)
unnamed: F1.2, TR1.P$1 (PRI1A)
unnamed: AC.2, TR1.P$4 (PRI2B)
unnamed: AC.1, F1.1
unnamed: R2.1, TR1.P$5 (SEC1A), TR1.P$7 (SEC2A)
unnamed: B1.AC1, R2.2
unnamed: C3.2, IC1.4 (BYP)
unnamed: LED.C, R1.2
unnamed: B1.+, L1.1
unnamed: C3.1, C4.+, C5.1, DC_OUT1.1, IC1.1 (OUT), IC1.2 (SENSE), LED.A
unnamed: L1.2, L2.1
unnamed: B1.AC2, TR1.P$6 (SEC1B), TR1.P$8 (SEC2B)
unnamed: C1.+, C2.1, IC1.5 (!SHDN), IC1.8 (IN), L2.2



Board: 2 copper layers, 82.9 x 53.3 mm, 17 parts (6 on the bottom side), 14 nets.

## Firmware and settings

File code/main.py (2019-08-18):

import digitalio
import board
import busio
from modules import MdacAttenuator, InputSelector, VolumeControl, InputControl

debug_mode = False

ir_input = digitalio.DigitalInOut(board.A0)
cs_input_selector = digitalio.DigitalInOut(board.A4)
cs_mdac = digitalio.DigitalInOut(board.A5)
spi = busio.SPI(board.SCK, MOSI=board.MOSI)
attenuator = MdacAttenuator(spi, cs_mdac, steps=128, debug=debug_mode)
selector = InputSelector(spi, cs_input_selector, debug=debug_mode)


volume_control = VolumeControl(
    pixel_pin=board.D13,
    encoder_pin_a=board.D11,
    encoder_pin_b=board.D12,
    attenuator=attenuator,
    debug=debug_mode
)

input_control = InputControl(
    pixel_pin=board.D10,
    encoder_pin_a=board.D7,
    encoder_pin_b=board.D9,
    selector=selector,
    input=4,
    debug=debug_mode
)

while True:
    volume_control.read_encoder()
    input_control.read_encoder()

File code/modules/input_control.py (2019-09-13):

# -*- coding: utf-8 -*-

import time
from .encoder_panel import EncoderPanel


class InputControl(EncoderPanel):
    '''
    Input control module
    '''
    def __init__(self, pixel_pin, encoder_pin_a, encoder_pin_b, selector, input=1, debug=False):
        super(InputControl, self).__init__(pixel_pin, encoder_pin_a, encoder_pin_b)
        self.selector = selector
        self.encoder_last_position = 0
        self.encoder_position = 0
        self.last_change_time = time.time()
        self.debug = debug
        self.mute_delay = 1
        self.counter_crossover_points = [int((i*21.17) + 1) for i in range(0, 6)]
        self.selector.select_input(input)
        self.counter = self.counter_crossover_points[input - 1]
        self.update_ring_colour()


    def _print(self, message):
        '''
        Small function for printing information is debug option is enabled
        '''
        if not self.debug:
            return
        else:
            print('input-control: {0}'.format(message))

    def update_ring_colour(self):
        '''
        Updates the ring colour based on the current encoder position counter and changes inputs
        '''
        if self.counter < 0:
            self.counter = 127
        if self.counter > 127:
            self.counter = 0

        pos = self.counter

        if pos < 0 or pos > 127:
            r = g = b = 0
        elif pos < 43:
            r = int(pos * 3)
            g = int(127 - pos*3)
            b = 0
        elif pos < 85:
            pos -= 43
            r = int(127 - pos*3)
            g = 0
            b = int(pos*3)
        else:
            pos -= 85
            r = 0
            g = int(pos*3)
            b = int(127 - pos*3)

        input = int(self.counter/21.17) + 1

        if self.counter in self.counter_crossover_points and self.selector.input_current != input:
            self.selector.select_input(input)
            self.flash_ring()

        self.last_change_time = time.time()
        self.fill_pixel_ring((int(r/8), int(g/8), int(b/8), 0))

    def flash_ring(self):
        '''
        Flashes the ring briefly to indicate a change
        '''
        self.ring.fill([8, 0, 0, 0])
        self.ring.fill([0, 8, 0, 0])
        self.ring.fill([0, 0, 8, 0])
        self.ring.fill([0, 0, 8, 8])
        return

    def read_encoder(self):
        '''
        Reads the position of the encoder and takes action
        '''
        if self.selector.mute_enabled:
            self._print('waiting for mute delay')
            time.sleep(self.mute_delay)
            self.selector.toggle_mute()

        self.encoder_position = self.encoder.position

        if self.counter not in self.counter_crossover_points and time.time() - self.last_change_time > 1:
            desired_point = self.counter_crossover_points[self.selector.input_current - 1]
            self._print('fading to: {0}'.format(desired_point))
            while self.counter not in self.counter_crossover_points:
                if self.selector.input_current == 1:
                    if self.counter > desired_point and self.counter < 106:
                        self.counter -= 1
                    else:
                        self.counter += 1
                elif self.counter > desired_point:
                    self.counter -= 1
                elif self.counter < desired_point:
                    self.counter += 1
                else:
                    continue
                self.update_ring_colour()
            self._print('fading done')

        if self.encoder_position == self.encoder_last_position:
            return

        if self.encoder_position > self.encoder_last_position:
            self.counter += 1
            self.update_ring_colour()

        elif self.encoder_position < self.encoder_last_position:
            self.counter -= 1
            self.update_ring_colour()

        self.encoder_last_position = self.encoder_position

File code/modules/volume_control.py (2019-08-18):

# -*- coding: utf-8 -*-

import time
from .encoder_panel import EncoderPanel


class VolumeControl(EncoderPanel):
    '''
    Volume control module
    '''
    def __init__(self, pixel_pin, encoder_pin_a, encoder_pin_b, attenuator, level=30, debug=False):
        super(VolumeControl, self).__init__(pixel_pin, encoder_pin_a, encoder_pin_b)
        self.attenuator = attenuator
        self.encoder_last_position = 0
        self.encoder_position = 0
        self.colour_level_pixel = 0
        self.pixel_max_brightness = 64
        self.colour_background = [0, 3, 3, 0]
        self.debug = debug
        self.fade_ring()
        time.sleep(1)
        self.fade_to_level(level)


    def _print(self, message):
        '''
        Small function for printing information is debug option is enabled
        '''
        if not self.debug:
            return
        else:
            print('volume-control: {0}'.format(message))

    def up(self):
        '''
        Increases level
        '''
        self.attenuator.up()
        self.write_single_pixel(*self._calculate_volume_ring(self.attenuator.level))

    def down(self):
        '''
        Decreases level
        '''
        self.attenuator.down()
        self.write_single_pixel(*self._calculate_volume_ring(self.attenuator.level))

    def fade_to_level(self, level):
        '''
        Fades to specifiied level
        '''
        self._print('fading to: {0}'.format(level))
        while self.attenuator.level < level:
            time.sleep(0.01)
            self.up()

        return

    def fade_ring(self):
        '''
        Fades ring to a low brightness
        '''
        self._print('fading')
        self.ring.fill(self.colour_background)
        return

    def unfade_ring(self):
        '''
        Fades ring to a low brightness
        '''
        self._print('unfading')
        self.fade_ring()
        for i in range(0, self.attenuator.level):
            self.write_single_pixel(*self._calculate_volume_ring(i))
            time.sleep(0.01)

        return

    def _calculate_volume_ring(self, level):
        '''
        Returns the RGBW values for the 16 NeoPixels given a volume level
        '''
        levels = len(self.attenuator.levels)
        pxl_val = levels / self.ring_num_neopixels
        start_offset = int(level / pxl_val)
        pixel_partially_lit = (level / pxl_val) - start_offset
        level_pixel = int(self.pixel_max_brightness * pixel_partially_lit)
        pixel_value = self.colour_background.copy()
        pixel_value[self.colour_level_pixel] = level_pixel

        return (start_offset + 1, pixel_value)

    def read_encoder(self):
        '''
        Reads the position of the encoder
        '''
        self.encoder_position = self.encoder.position

        if self.encoder_position == self.encoder_last_position:
            return

        if self.encoder_position > (self.encoder_last_position + 1):
            self.up()
            self.encoder_last_position = self.encoder_position

        elif self.encoder_position < (self.encoder_last_position - 1):
            self.down()
            self.encoder_last_position = self.encoder_position

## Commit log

2018-12-13 adding new circuit python modules for each component
2018-12-13 finished circuitpython test code for input selector
2018-12-16 misc fixes for input selector
    [input_selector.py]
2018-12-28 reorganising PCBs and updating todo
    [encoder-panel.kicad_pcb, encoder-panel.sch, input-selector.brd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]
2019-01-05 Updating all schematics to kicad (#2)
    * adding kicad rcs-panel
    * update encoder panel
    * updating 3 PCBs to kicad
    * small input selector update
    * Add new text
    * Misc updates to 3 PCBs
    * Fixing input selector panasonic relay footprint
    * update mcu-board
    [encoder-panel.kicad_pcb, input-selector.brd, input-selector.kicad_pcb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]
2019-01-05 Switching relay type to Omron G6J relays (#3)
    Since I can't find a source for the others
    [input-selector.kicad_pcb, input-selector.sch]
2019-01-05 adding BoMs, images and small design updates (#4)
    [input-selector.kicad_pcb, input-selector.sch, mdac-attenuator.kicad_pcb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]
2019-01-22 adding digital and analog PSUs (#6)
    [psu-analog.brd, psu-analog.sch, psu-digital.brd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]
2019-01-26 New RCA board (#7)
    * updating PCB after creating new library for newer 805 RCAs
    * fix for mounting holes
    [rca-panel.kicad_pcb, rca-panel.sch]
2019-01-29 Addinng PCB for MCU board (#8)
    * Updating mcu-board PCB
    * renaming some nets
    * starting to fix silkscreen
    * change pad/mask clearance
    * misc updates
    * adding images
    * update readme
    [mc-connector-board.kicad_pcb, mc-connector-board.sch, mcu-board.kicad_pcb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]
2019-02-02 Updating encoder panel PCBs (#9)
    * updating encoder panel
    * misc fixes
    * adding oshpark page break
    * renaming symbol to correct name
    * removing old libraries
    * tidying up footprints
    * finishing
    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
    [encoder-panel.kicad_pcb, encoder-panel.sch]
2019-03-09 adding prototype images
2019-03-17 adding more prototype photos
2019-03-24 Misc code fixes, update todo, some readme, (#10)
    * code updates for testing
    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
    [input_selector.py, input_selector_tester.py, main.py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]
2019-03-27 Updating mcu-board to not use pin 5 (#12)
    [mcu-board.kicad_pcb, mcu-board.sch]
2019-04-02 Finishing some code functionality and updating readme (#11)
    * Finishing some code functionality and updating readme
    * fixes after testing
    * updates
    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
    [encoder_panel.py, input_selector.py, main.py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]
2019-04-30 Adding more images and updating code with a working version (#14)
    * getting better
    * some working code now
    * updating images
    * remove line
    * MISC
    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
    [diagram.fzz]
2019-06-25 adding a gif
    add enclosure info
    update bom to m4
    fix MDAC level bug
    switching arrangement of modules
    removing old arduino sketch
    misc changes
    adding ring fading after timeout
    moving dirs outside of images dir
    update todo
    more code changes
    updates to images
    typo in image path
    add prototype image
    add encoder_panel back
    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
    [front.stl, knob.stl, preamp-two-enclosure.f3d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]
2019-07-20 updating 3d files
    [bearing-bracket.stl, knob.stl, preamp-two-enclosure.f3d]
2019-08-10 Switch to use object inheritance for the encoder panel modules (#16)
    * switch to use object inheritance for the encoder panel
    to reduce duplicated code
    * rewrite of colour calculation
    * changing input control LED style
    * finally colours working nicely
    * fix debug mode
    * tidy up
    * misc changes
    [encoder_panel.py, input_control.py, main.py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]
2019-08-18 General tidy up (#17)
    [diagram.fzz]
2019-09-13 Updating bearing bracket and mute delay (#18)
    [bearing-bracket.stl, preamp-two-enclosure.f3d]
2021-11-08 Update README.md (#20)
    https://forum.kicad.info/t/warning-avoid-all-links-to-kicad-pcb-org-use-kicad-org/31521/
